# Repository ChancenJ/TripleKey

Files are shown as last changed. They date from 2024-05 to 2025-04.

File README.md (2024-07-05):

# TripleKey

## 项目说明

基于ESP32-S3的蓝牙小键盘，具有时间显示、天气预报、实时股票、宏键盘、蓝牙键盘、倒计时、人在感应、米家智能家居控制等功能。

立创开源地址：[嘉立创EDA开源硬件平台](https://oshwhub.com/chancenj/superkey)

Github地址：[Gituhb](https://github.com/ChancenJ/TripleKey)

Gitee地址：[Gitee](https://gitee.com/chancenj/triplekey)

## 开源协议

CC BY-NC-SA 4.0（署名-非商业性使用-相同方式共享 4.0 国际）

## 项目功能

- 时间显示、实时天气、天气预报、气象预警、实时股票等信息显示。
- 蓝牙键盘、宏键盘、快捷键、快捷网页、媒体控制等控制电脑功能。
- 倒计时等计时功能。
- 通过网页对多项功能自定义配置。
- 【可选，需N16R2】照片轮播功能。
- 【可选，需额外硬件】接入米家，作为米家无线开关和状态寄存器。
- 【可选，需额外硬件】人体存在感应，有人时自动亮屏，无人时自动熄屏，有无人状态接入米家，可搭配米家智能家居设备进行智能联动。

功能展示：[功能展示](https://b23.tv/3Hd1zba)

主体装配视频：[主体装配视频](https://b23.tv/uhOZp0Y)

米家拓展详解：[米家拓展详解](https://b23.tv/kM9jVT6)

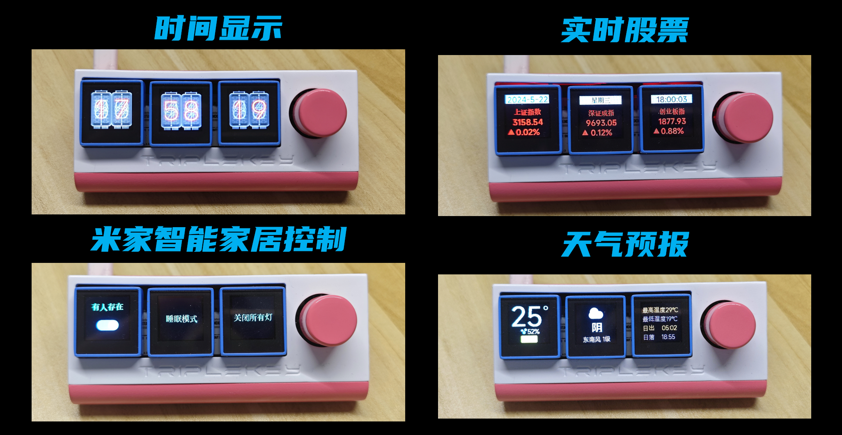
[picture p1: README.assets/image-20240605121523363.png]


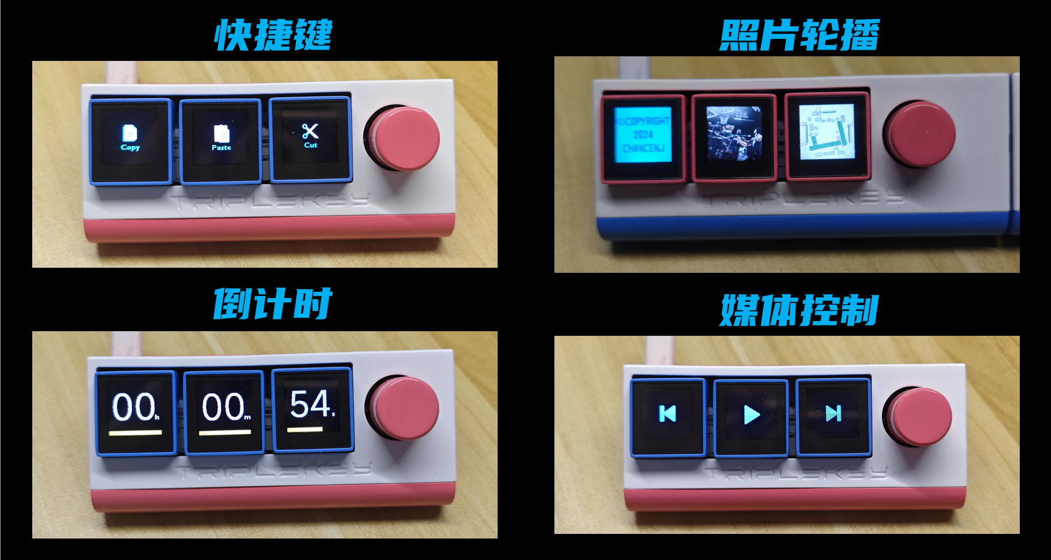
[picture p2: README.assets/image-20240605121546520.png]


## 项目属性

本项目衍生自MakerM0的开源项目[3Plus_v2](https://github.com/MakerM0/3Plus_v2)，优化了PCB布局，替换部分器件，引出拓展接口，增加米家拓展部分，接入米家平台，增加人体存在传感器；更换屏幕方案，大幅降低屏幕成本；重新设计外壳，增加米家拓展部分外壳；在其代码框架基础上增加实时天气、天气预报、气象灾害预警、实时股票信息、米家设备控制、照片轮播、倒计时、WebServer自定义配置、网页后台、人体存在检测、固件检测升级，增加中文UI，优化快捷键功能，优化部分代码结构，修复时钟和快捷网页BUG，修复开机闪屏，去除冗余代码。

仅对源代码进行比较（不包含引用库文件，未包含更多所需data变化），根据git数据，原项目总计7277行，本项目总计12676行，相比变化10117行，其中增加7758行，删除2359行。详见附录。



## 硬件准备

### 硬件说明

#### 主控

ESP32-S3-WROOM-1-N8R2或ESP32-S3-WROOM-1-N16R2。区别在于后者拥有更多ROM，可实现更多功能。当前N16R2对应固件额外支持照片轮播，可自行上传照片在屏幕上显示。建议使用成本略高的N16R2，8MB版本受限于其空间，可能不再更新固件。

#### 旋转编码器

立创EDA中使用阿尔卑斯阿尔派EC11J1524413，成本高昂。若需要降低成本，可选择廉价普通插件编码器改贴片，详见后文额外BOM表。区别在于质感和焊接方式，编码器限位值和正反方向不同，可进行自定义配置。

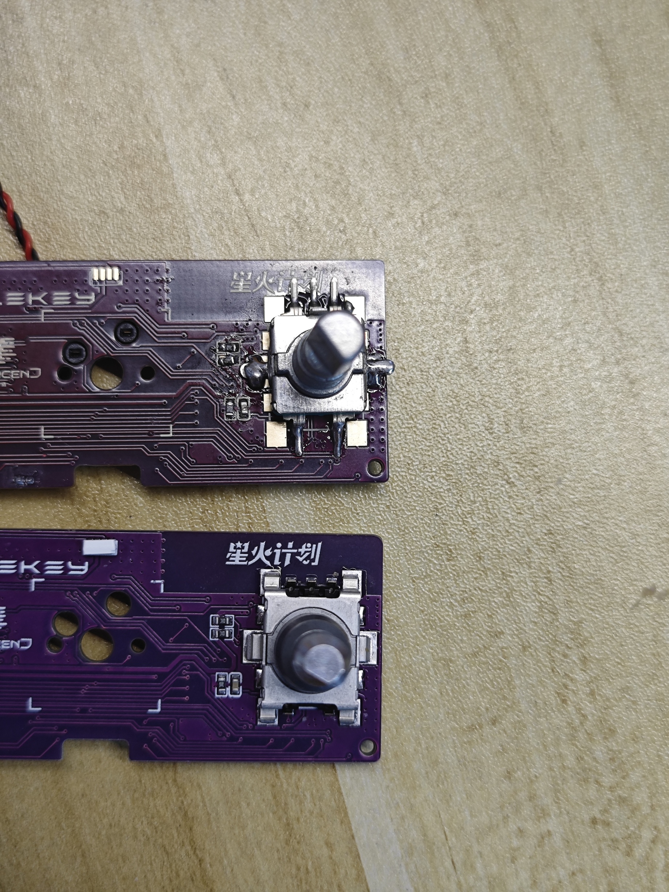
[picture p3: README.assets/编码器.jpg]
编码器


#### 屏幕

- 方案一：0.85英寸长排焊接12PIN（驱动GC9107）直达链接：https://m.tb.cn/h.gXZoDytOg9CEca7?tk=Qb9vWtzlGgj

此方案一定需要定位板，焊接及组装方式详见后文。

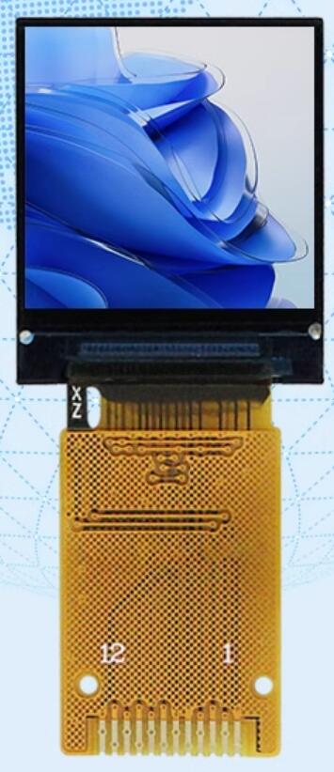
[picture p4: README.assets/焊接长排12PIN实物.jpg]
焊接长排12PIN实物
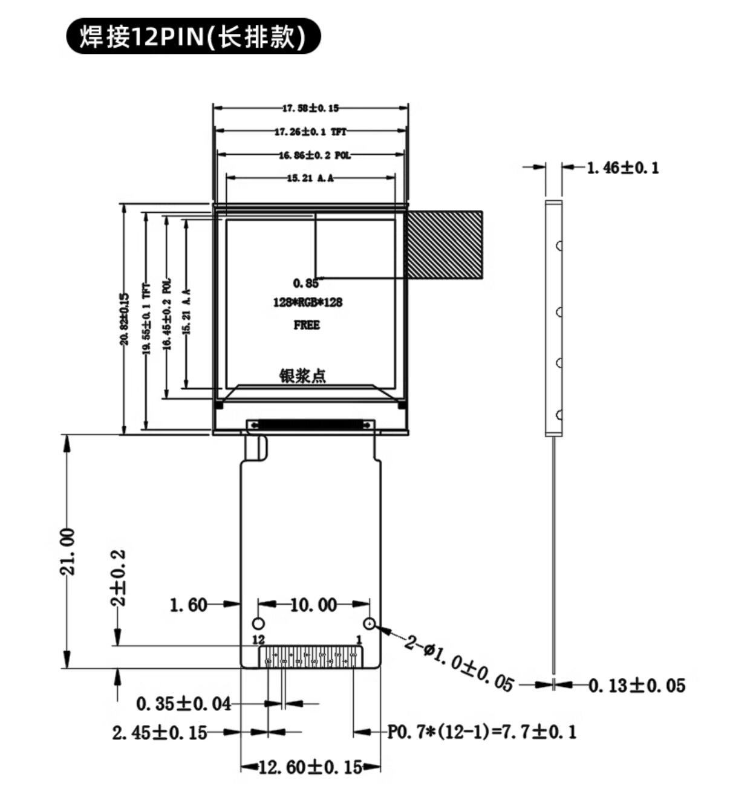
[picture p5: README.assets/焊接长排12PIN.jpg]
焊接长排12PIN


- 方案二：0.85英寸长排插接12PIN（驱动NV3023）直达链接：https://m.tb.cn/h.gc6dU3OZHkynqdG?tk=nWm8WtzFscl

此方案定位板非必须，但为了按键稳固，依然推荐使用定位板但无需焊接，组装方式详见后文。

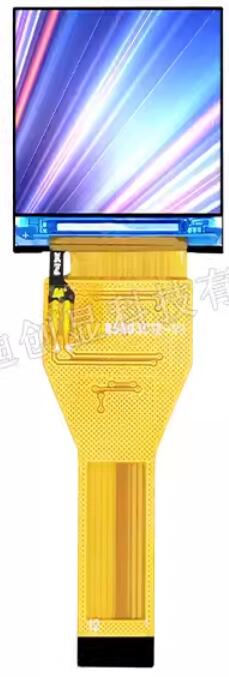
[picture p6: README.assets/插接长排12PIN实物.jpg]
插接长排12PIN实物
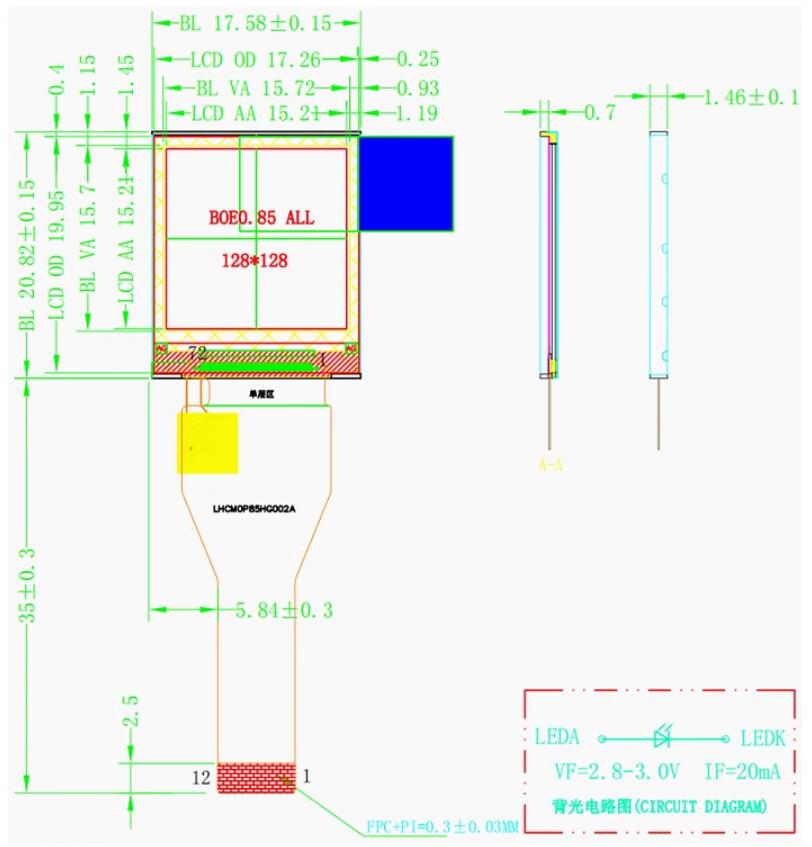
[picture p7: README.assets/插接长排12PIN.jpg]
插接长排12PIN


==区别在于两者成本，方案一成本约15元，但需要焊接屏幕和FPC排线座，方案二成本约30元，直接插接主板。两者固件不同，功能一致。==

### 硬件准备

#### PCB

PCB共分为主板、定位板、拓展板，工程中已标明。

主板必备，定位板强烈推荐（屏幕方案一必备），拓展板可选（用于接入米家和人在感应）。

**主板**

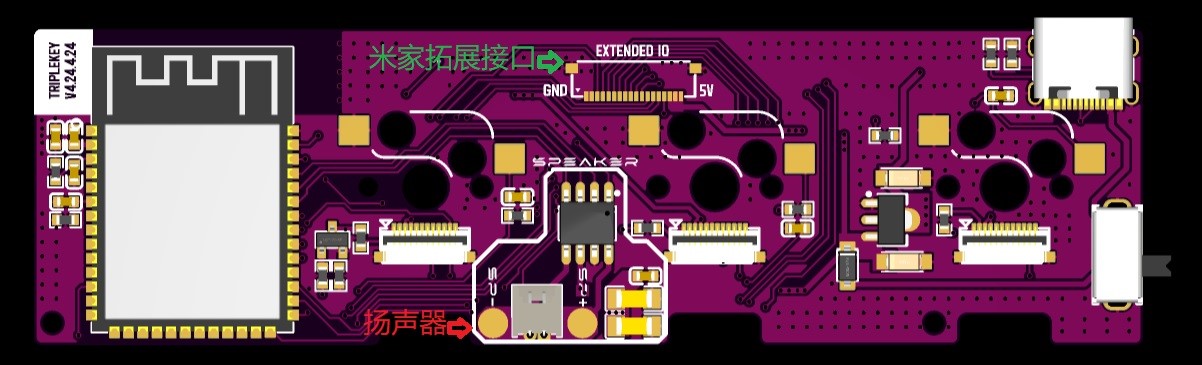
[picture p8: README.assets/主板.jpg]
主板


扬声器与米家拓展接口已标出，可选择性焊接。

**定位板**

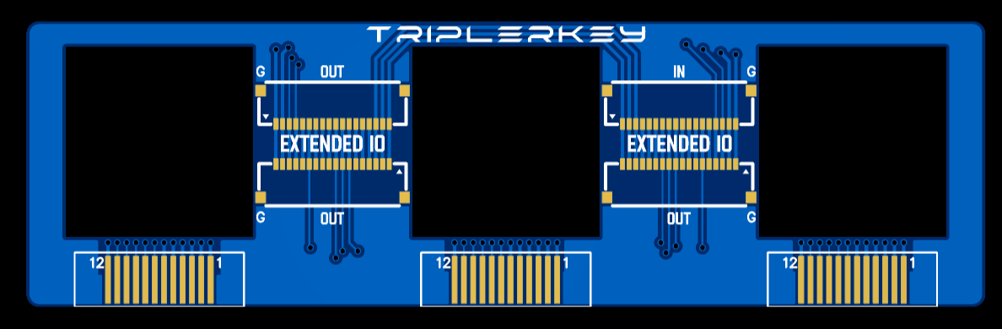
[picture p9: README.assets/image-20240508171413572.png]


用于固定键轴和方案一的屏幕连接。（方案一如下图所示焊接屏幕、安装键轴，屏幕方案二无需焊接）

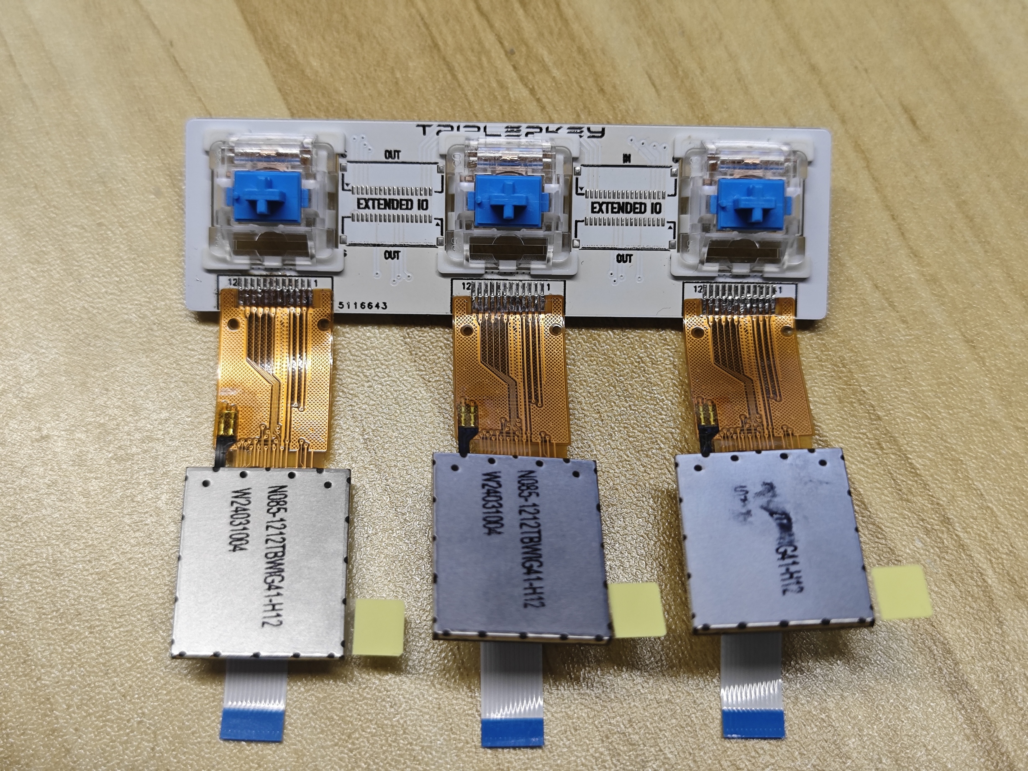
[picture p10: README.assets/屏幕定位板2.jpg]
屏幕定位板2


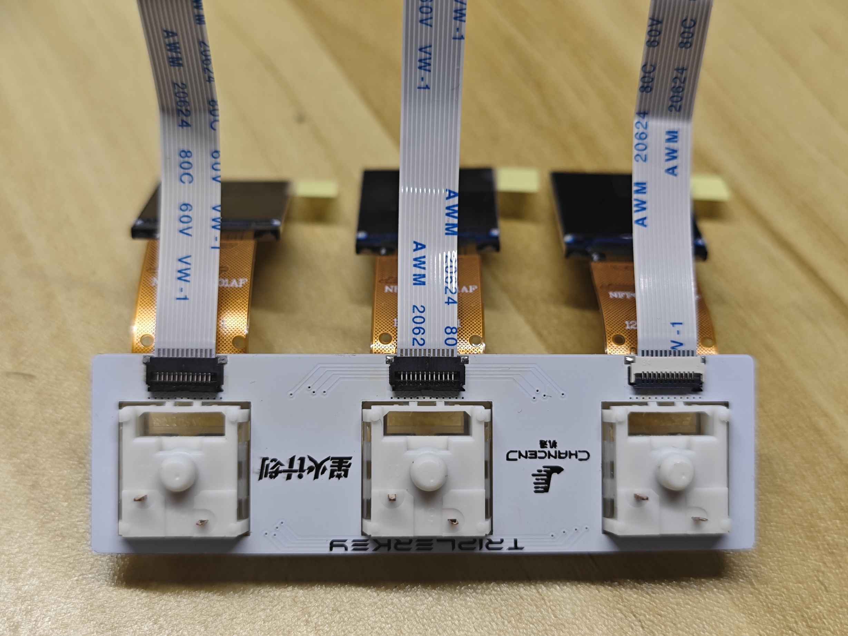
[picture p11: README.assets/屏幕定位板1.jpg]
屏幕定位板1


**米家拓展板**

------

- 20240605更新

对米家拓展方案进行了改进，放入一个外壳，详见[TripleKey小键盘米家拓展方案改进版](https://oshwhub.com/chancenj/triplekey_v2_1)。

**如果你看到了此段内容，不管是否需要米家，都推荐直接使用改进版，只有米家拓展方案不同。**

**改进内容**

将主板与拓展板放入一个外壳，改用**HLK-LD2410B**（[直达链接](https://m.tb.cn/h.g484iFO)）作为人体存在传感器。

如果在原项目中使用了**拓展方案2**进行3D打印，可直接打板**【拓展方案3】米家及人在传感器拓展_贴**放入原外壳。

如果需要对外壳重新3D打印，请改用本项目改版外壳（仅主体外壳不同），打板**【拓展方案3】米家及人在传感器拓展_插**适用新外壳。（贴片版也可使用，但插件排母更方便购买）

主要区别为排母是贴片还是插件，原版拓展方案2外壳受限于支撑PCB部分形状，只能使用贴片排母；新版外壳进行了挖空，贴片排母与插件排母均可使用。

详细解释与装配视频：[米家拓展详解](https://b23.tv/kM9jVT6)

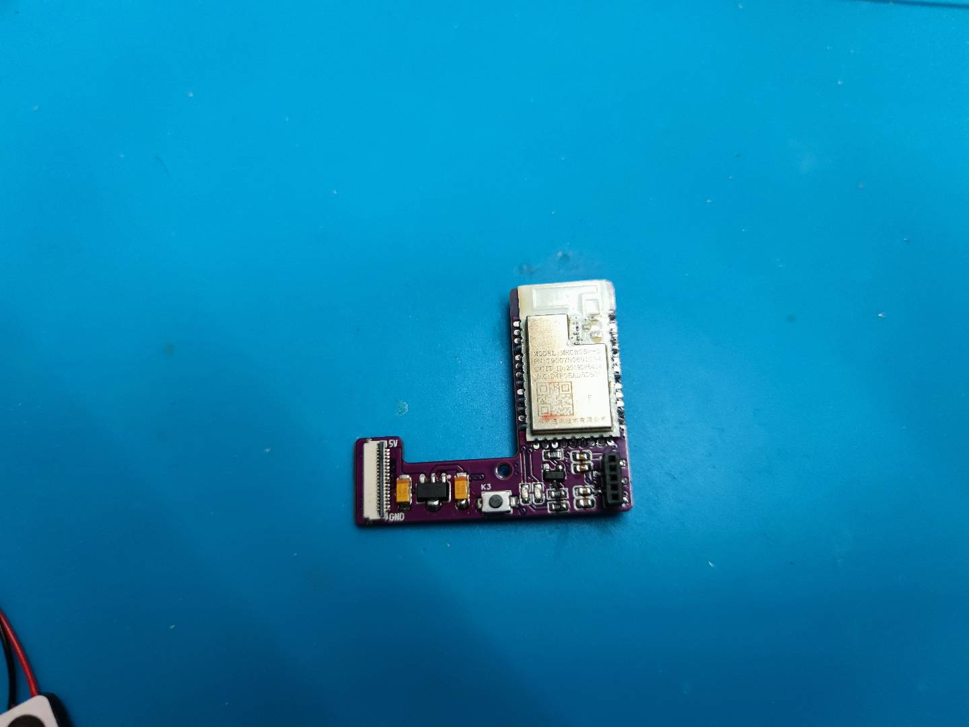
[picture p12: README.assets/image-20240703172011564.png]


------

#### 3D打印外壳

附件下载外壳文件进行打印。

如果使用拓竹等常见FDM3D打印机，请使用FDM版本。

如果在嘉立创3D打印下单，请使用SLA版本。

------

- 20240605更新

对米家拓展方案进行了改进，放入一个外壳，详见[TripleKey小键盘米家拓展方案改进版](https://oshwhub.com/chancenj/triplekey_v2_1)，原版方案2外壳依旧可用。

**如果你看到了此段内容，不管是否需要米家，都推荐直接使用改进版，只有米家拓展方案不同。**

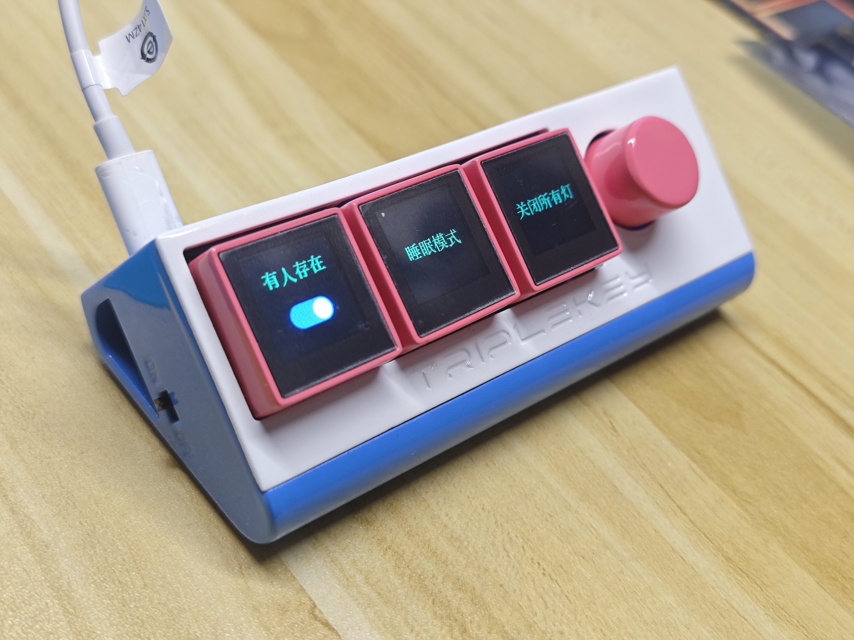
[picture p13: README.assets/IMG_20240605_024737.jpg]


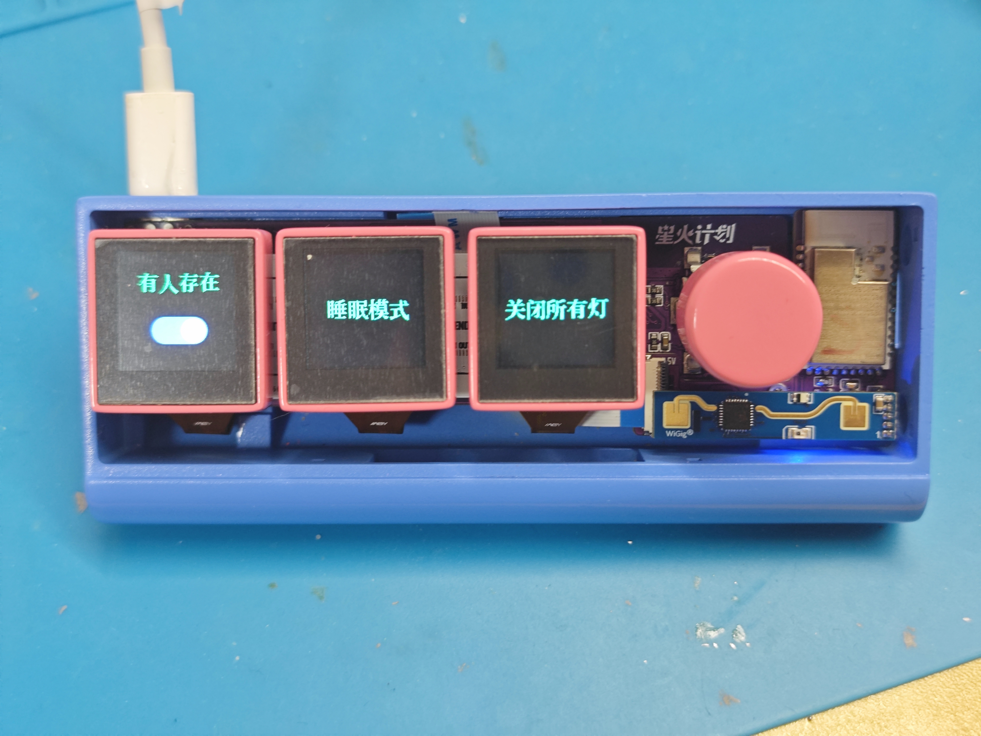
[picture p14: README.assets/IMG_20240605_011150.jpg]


------

#### 面板

使用工程中面板文件，自行选择修改需要的颜色和方案，删掉不需要的颜色，进行面板下单。

设置如下图：（注意：立创面板定制已改版，不再限制尺寸，未实践过新版）

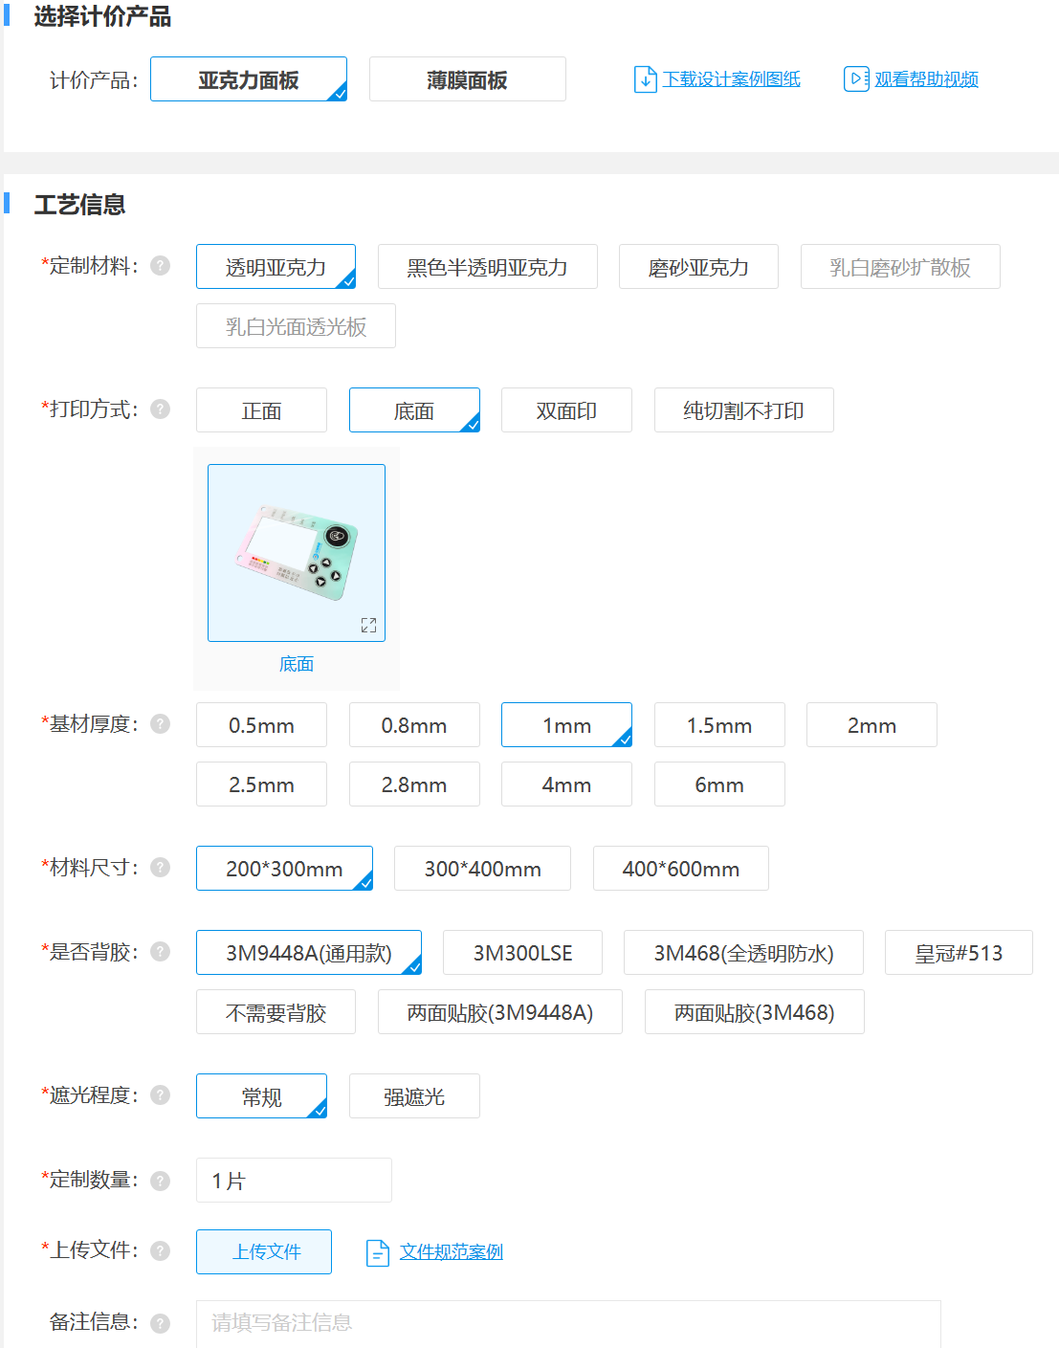
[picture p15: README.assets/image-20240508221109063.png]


#### 额外BOM

[docs目录下额外BOM.xlsx文件](./docs)

表中不包含阻容、二极管、稳压器等常见器件，自行根据立创导出的BOM解决。多数器件可在优信电子买到。

## 软件说明

### 固件烧录

使用乐鑫的[flash download tool](https://www.espressif.com.cn/sites/default/files/tools/flash_download_tool_3.9.5_0.zip)工具，固件有多个版本，根据自身硬件自行选择适配版本。

| 主控 | 屏幕 | 固件 |
| --- | --- | --- |
| ESP32-S3-WROOM-1-N16R2 | NV3023 | firmware_NV3023_16MB.bin |
| ESP32-S3-WROOM-1-N16R2 | GC9107 | firmware_GC9107_16MB.bin |
| ESP32-S3-WROOM-1-N8R2  | NV3023 | firmware_NV3023_8MB.bin  |
| ESP32-S3-WROOM-1-N8R2  | GC9107 | firmware_GC9107_8MB.bin  |

按照下图方式进行安装

1. 在上电前，按住左数第三个按钮，然后上电，进入烧录模式，会听到设备管理器提示音。
2. 打开工具，按下图设置。
3. 下载成功后，手动开关重启，按照提示进行连接设备热点配置WIFI。

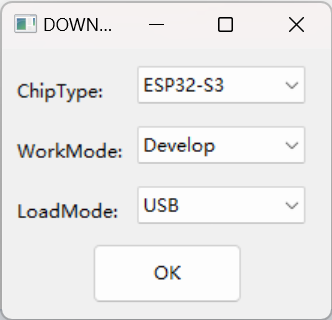
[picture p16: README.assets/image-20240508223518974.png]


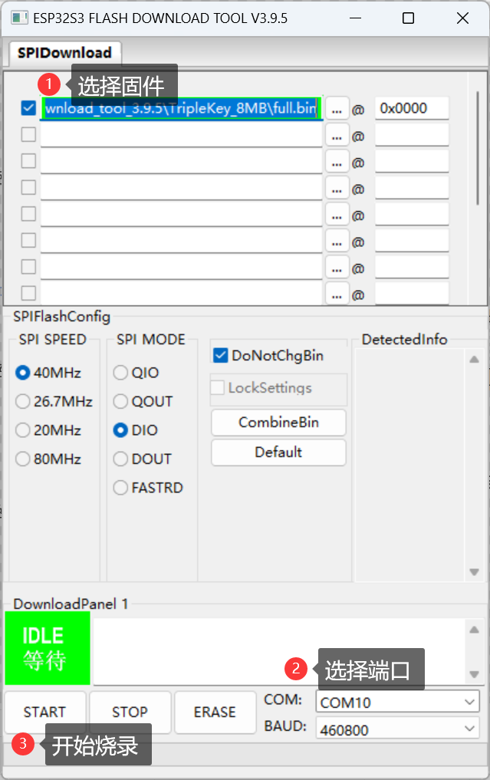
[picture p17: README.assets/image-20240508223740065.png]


### 开始使用

固件烧录完成后开机，连接设备自带热点，进入屏幕提示网址（手机连接后一般自动进入）配置WIFI。启动时按住中键可重新配置，启动时按住右键可进入OTA模式。

连接电脑蓝牙即可使用。

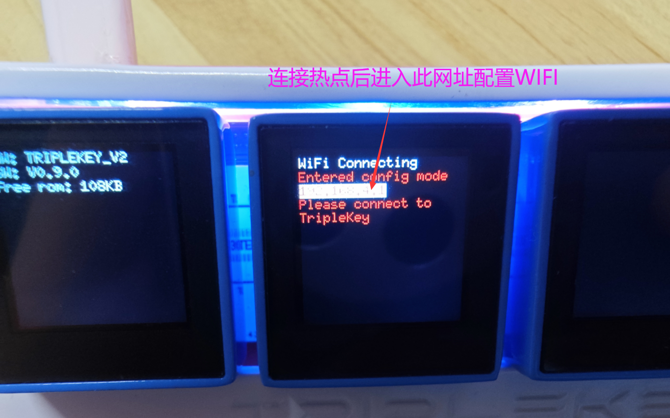
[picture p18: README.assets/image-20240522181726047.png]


### 功能说明与更新日志

详见[软件说明](./Software/README.md)

## 实物展示

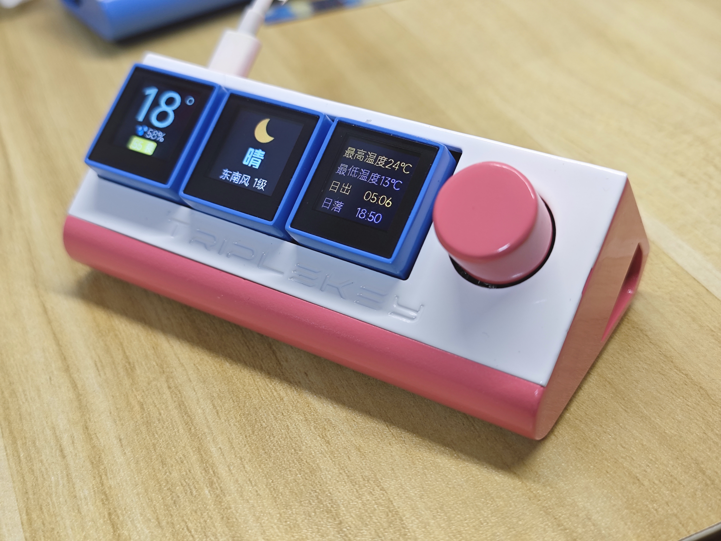
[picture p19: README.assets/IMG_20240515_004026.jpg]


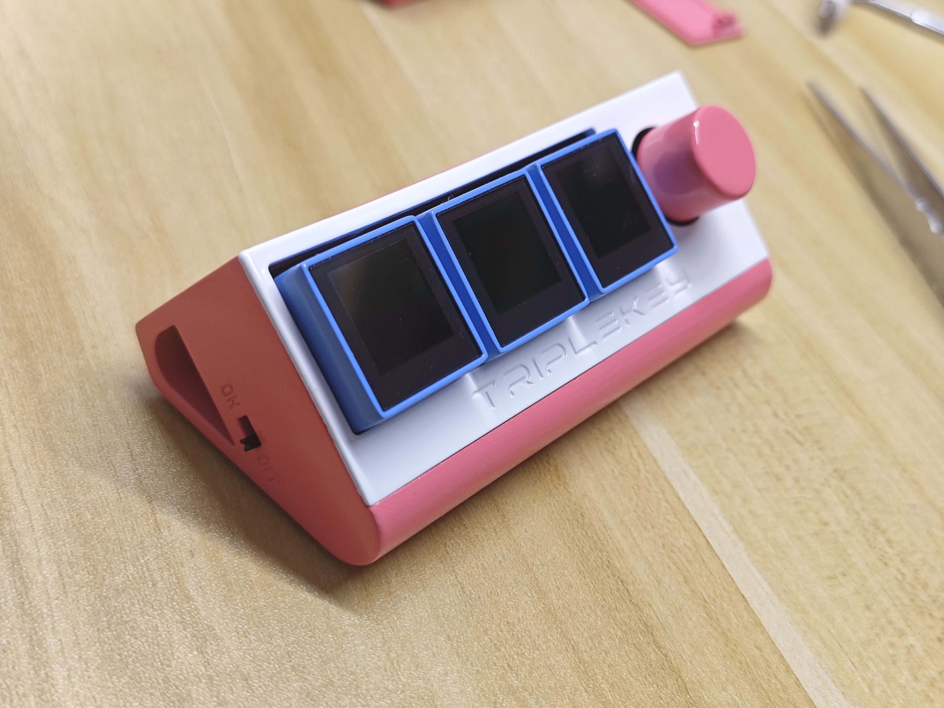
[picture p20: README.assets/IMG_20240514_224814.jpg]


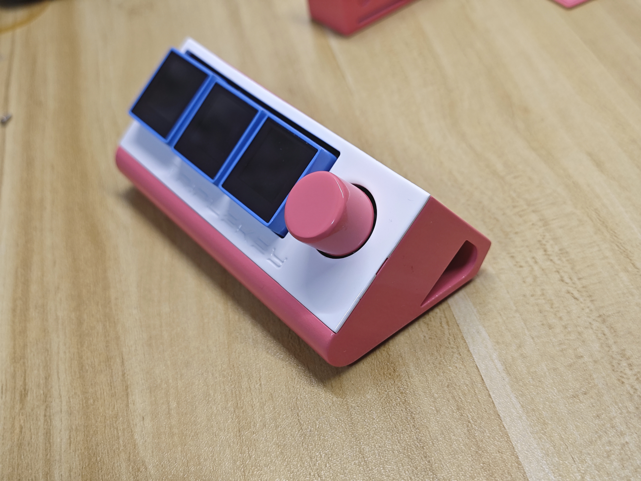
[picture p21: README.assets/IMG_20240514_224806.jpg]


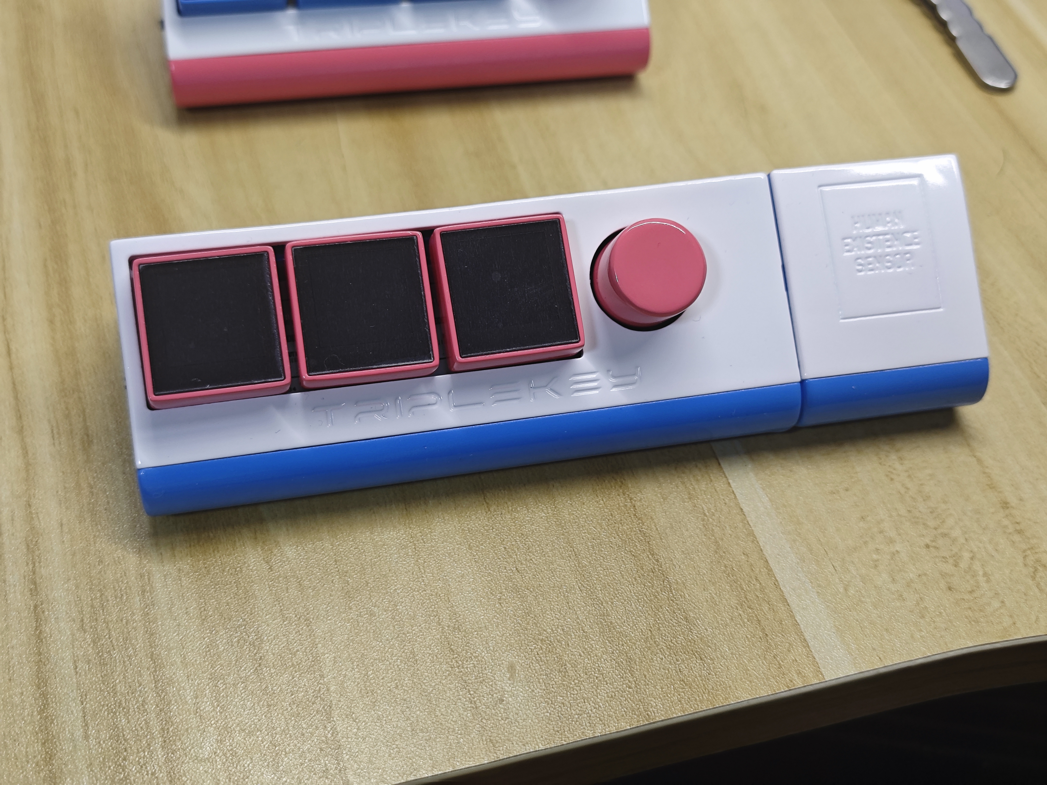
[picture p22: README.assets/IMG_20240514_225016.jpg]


## 附录

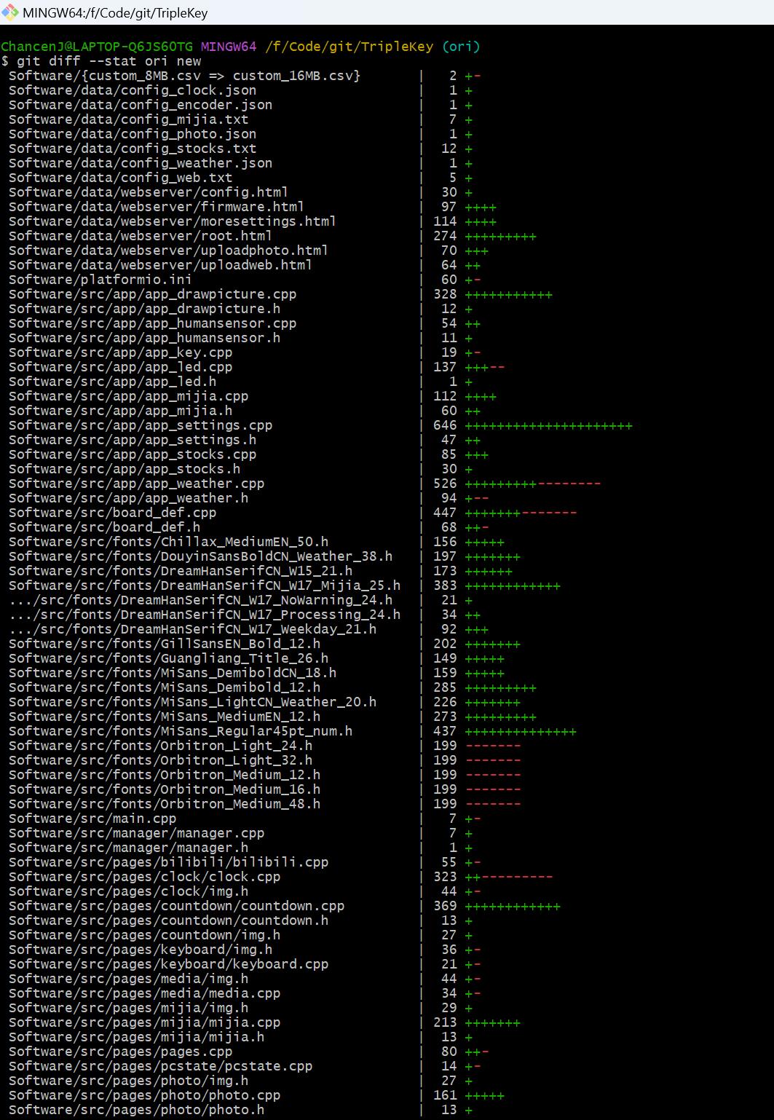
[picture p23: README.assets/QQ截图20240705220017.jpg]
QQ截图20240705220017


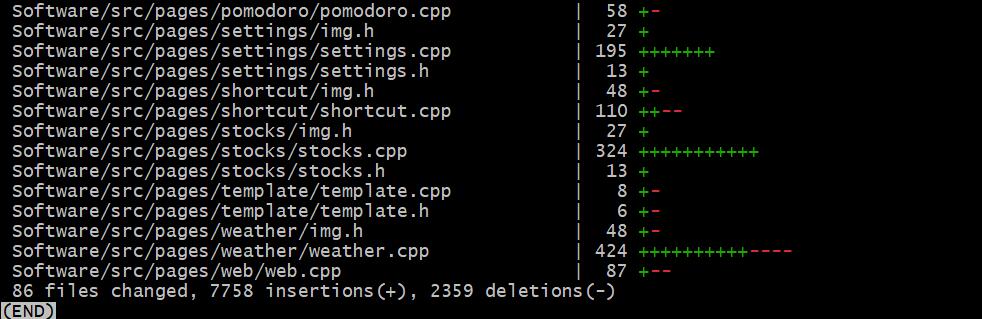
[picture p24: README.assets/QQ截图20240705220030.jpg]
QQ截图20240705220030


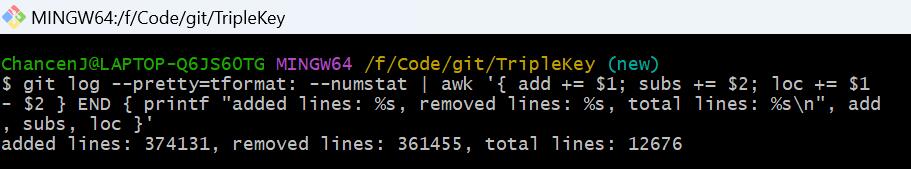
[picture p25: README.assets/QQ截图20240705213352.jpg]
QQ截图20240705213352


QQ截图20240705220120

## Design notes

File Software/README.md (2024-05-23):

## 软件说明

### 功能说明

#### 0.启动

- 首次启动，屏幕提示连接自身热点，进行WIFI配置。启动时按住中键可重新配置，启动时按住右键进入OTA模式。

- 启动后任意页面长按旋钮，进入菜单；旋转旋钮，调整内容；单击对应按键，进入相应页面。

#### 1.时间

| 按键/操作 | 单击 | 双击 | 长按 | 左旋 | 右旋 |
| :---: | :--: | :---: | :---: | :---: | :---: |
| **左键**  | | 进入天气 | 进入米家 | —— | —— |
| **中键**  | 报时 | | | —— | —— |
| **右键**  | | | | —— | —— |
| **旋钮**  | | | 进入菜单 | 调整样式 | 调整样式 |

#### 2.天气

- 实时天气、三日天气预报、气象灾害预警

| 按键/操作 | 单击 | 双击 | 长按 | 左旋 | 右旋 |
| :---: | :---: | :--: | :---: | :---: | :---: |
| **左键**  | | | | —— | —— |
| **中键**  | | | | —— | —— |
| **右键**  | | | | —— | —— |
| **旋钮**  | 返回时间页面 | | 进入菜单 | 调整显示内容 | 调整显示内容 |

#### 3.股票

- 2分钟更新一次数据，自动轮播。呼吸灯颜色随涨跌变化。

| 按键/操作 | 单击 | 双击 | 长按 | 左旋 | 右旋 |
| :---: | :--: | :--: | :---: | :---: | :---: |
| **左键**  | | | | —— | —— |
| **中键**  | | | | —— | —— |
| **右键**  | | | | —— | —— |
| **旋钮**  | | | 进入菜单 | 调整显示内容 | 调整显示内容 |

#### 4.米家（对应固件、连接拓展）

- 米家无线开关功能（米家八键复合开关4情景+4开关），可接入米家控制米家智能家居设备，可显示开关状态，与米家同步，共可设置4开关+12场景（4键单击双击长按）；
- 人体存在传感器（海凌科人体存在传感器HLK-2410C），绑定米家无线开关KEY1，有人存在则KEY1开，无人则KEY1关，有人无人状态实时同步，通过米家可设置智能场景联动米家设备。（有人无人检测相关配置使用海凌科官方APP HLKRadarTool）
- 根据有人无人状态自动开关屏幕和LED灯功能。

| 按键/操作 | 单击 | 双击 | 长按 | 左旋 | 右旋 |
| :---: | :---: | :--: | :---: | :---: | :---: |
| **左键**  | 对应操作 | | | —— | —— |
| **中键**  | 对应操作 | | | —— | —— |
| **右键**  | 对应操作 | | | —— | —— |
| **旋钮**  | 返回时间页面 | | 进入菜单 | 调整操作内容 | 调整操作内容 |

#### 5.照片（ESP32-S3-WROOM-1-N16R2支持，N8R2不支持）

-  通过网页上传，自动轮播

| 按键/操作 | 单击 | 双击 | 长按 | 左旋 | 右旋 |
| :---: | :--: | :--: | :---: | :---: | :---: |
| **左键**  | | | | —— | —— |
| **中键**  | | | | —— | —— |
| **右键**  | | | | —— | —— |
| **旋钮**  | | | 进入菜单 | 调整显示内容 | 调整显示内容 |

#### 6.键盘

- 通过蓝牙连接电脑，用作蓝牙键盘

| 按键/操作 | 单击 | 双击 | 长按 | 左旋 | 右旋 |
| :---: | :---: | :--: | :---: | :---: | :---: |
| **左键**  |  输入对应字符  | | | —— | —— |
| **中键**  |  输入对应字符  | | | —— | —— |
| **右键**  |  输入对应字符  | | | —— | —— |
| **旋钮**  | 切换大小写数字 | | 进入菜单 | 调整显示内容 | 调整显示内容 |

#### 7.快捷键

- 通过蓝牙连接电脑，使用快捷键（复制、剪切、粘贴、显示桌面、全选、切屏、撤销、刷新等）

| 按键/操作 | 单击 | 双击 | 长按 | 左旋 | 右旋 |
| :---: | :---: | :--: | :---: | :---: | :---: |
| **左键**  | 对应快捷键 | | | —— | —— |
| **中键**  | 对应快捷键 | | | —— | —— |
| **右键**  | 对应快捷键 | | | —— | —— |
| **旋钮**  | | | 进入菜单 | 调整显示内容 | 调整显示内容 |

#### 8.网页

-  通过蓝牙连接电脑，快捷启动浏览器进入网页。

| 按键/操作 | 单击 | 双击 | 长按 | 左旋 | 右旋 |
| :---: | :---: | :--: | :---: | :---: | :---: |
| **左键**  | 进入对应网页 | | | —— | —— |
| **中键**  | 进入对应网页 | | | —— | —— |
| **右键**  | 进入对应网页 | | | —— | —— |
| **旋钮**  | | | 进入菜单 | 调整显示内容 | 调整显示内容 |

#### 9.多媒体

- 通过蓝牙连接电脑，控制播放暂停、下一首、上一首、音量。

| 按键/操作 | 单击 | 双击 | 长按 | 左旋 | 右旋 |
| :---: | :---: | :--: | :---: | :---: | :---: |
| **左键**  | 上一首 | | | —— | —— |
| **中键**  | 播放/暂停 | | | —— | —— |
| **右键**  | 下一首 | | | —— | —— |
| **旋钮**  | 静音/解除静音 | | 进入菜单 | 调低音量 | 调高音量 |

#### 10.哔哩哔哩

- 一键三连、开关弹幕、全屏观看

| 按键/操作 | 单击 | 双击 | 长按 | 左旋 | 右旋 |
| :---: | :---: | :--: | :---: | :---: | :---: |
| **左键**  | 一键三连 | | | —— | —— |
| **中键**  | 开关弹幕 | | | —— | —— |
| **右键**  | 全屏观看 | | | —— | —— |
| **旋钮**  | 静音/解除静音 | | 进入菜单 | 调低音量 | 调高音量 |

#### 11.倒计时

- 双击旋钮进入设置模式，按下时分秒对应按键，数字闪烁，旋转旋钮可调节设定时间，单击旋钮开始/暂停/继续，退出倒计时页面继续计时。
- 底部进度条

| 按键/操作 | 单击 | 双击 | 长按 | 左旋 | 右旋 |
| :---: | :---: | :---: | :---: | :---: | :---: |
| **左键**  |  设置时 | | | —— | —— |
| **中键**  |  设置分 | | | —— | —— |
| **右键**  |  设置秒 | | | —— | —— |
| **旋钮**  | 开始/暂停 | 进入设置模式 | 进入菜单 | 调小设定时间 | 调大设定时间 |

#### 12.番茄钟

| 按键/操作 | 单击 | 双击 | 长按 | 左旋 | 右旋 |
| :---: | :---: | :--: | :---: | :--: | :--: |
| **左键**  | 计时开始/暂停 | | |  ——  |  ——  |
| **中键**  | 计时开始/暂停 | | |  ——  |  ——  |
| **右键**  | 计时开始/暂停 | | |  ——  |  ——  |
| **旋钮**  | | | 进入菜单 | | |

#### 13.设置

- 根据屏幕提示进入网页，进行自定义设置，可进行天气、股票、米家、快捷网页、上传照片、编码器等设置。

| 按键/操作 | 单击 | 双击 | 长按 | 左旋 | 右旋 |
| :---: | :---: | :--: | :---: | :--: | :--: |
| **左键**  |  快捷进入设置页面  | | |  ——  |  ——  |
| **中键**  | | | 重启设备 |  ——  |  ——  |
| **右键**  | 快捷进入仓库发行版 | | |  ——  |  ——  |
| **旋钮**  | | | 进入菜单 | | |

### 更新历史

#### 20240320 【V0.0.1】

- 初始版本

#### 20240326 【V0.1.x】

- V0.1.0 增加实时股票功能，股票页显示当前时间、股票名称、当前价格、涨跌幅，每2分钟更新一次，股票页每10秒自动切换，旋钮可手动切换。
- v0.1.1 增加股票页红绿呼吸灯，上涨为红，下跌为绿。
- V0.1.3 股票页显示日期、星期、时间。

#### 20240329 【V0.2.x】

- V0.2.0 天气功能完全重构，采用和风天气API，开机时长按中间键进入WIFI配置页可配置城市（输入拼音）和密钥（和风天气官网免费获取）。天气页显示当前温度、相对湿度、空气质量、天气状况、风向风力、最高最低温度、日出日落时间，旋钮可切换显示三天天气预报。

#### 20240410 【V0.3.x】

- V0.3.0 增加米家无线开关功能（米家八键复合开关4情景+4开关），可接入米家控制米家智能家居设备，可显示开关状态，与米家同步，共可设置4开关+12场景（4键单击双击长按）；增加人体存在传感器，绑定米家无线开关KEY1，有人存在则KEY1开，无人则KEY1关，有人无人状态实时同步，通过米家可设置智能场景联动米家设备。（*增加硬件：米家八键复合开关模组MHCB05P-B、海凌科人体存在传感器HLK-2410C、I2C拓展芯片CH423S。集合为米家拓展配件，通过拓展外设插口接入）
- V0.3.8 增加根据有人无人状态自动开关屏幕和LED灯功能。（有人无人检测相关配置使用海凌科官方APP HLKRadarTool）

#### 20240418 【V0.4.x】

- V0.4.0 增加自定义配置功能，连接WIFI后，进入设置页面，可在浏览器输入IP地址或扫描二维码进入配置页，对天气、股票、米家、快捷网页进行自定义配置，保存后即时生效。
- V0.4.3 增加整点报时可选项（更多设置Web页）。
- V0.4.4 增加时钟主题自动切换可选项。
- V0.4.10 增加旋转编码器设置，设置WIFI时或进入设置页-更多设置可对旋转编码器进行配置，旋转编码器限位值为2（阿尔卑斯阿尔派EC11J1524413）或4（普通插改贴编码器），若编码器操作逻辑相反，可设置反向。

#### 20240504 【V0.5.x】

- V0.5.0 【N16R2适配功能】增加照片播放功能，可进入设置页-更多设置对照片进行上传和删除，可设置是否自动轮播。

#### 20240505 【V0.6.x】

- V0.6.0 天气功能增加气象灾害预警信息

#### 20240506 【V0.7.x】

- V0.7.0 增加倒计时功能，双击旋钮进入设置模式，按下时分秒对应按键，数字闪烁，旋转旋钮可调节设定时间，单击旋钮开始/暂停/继续，退出倒计时页面继续计时。

#### 20240511 【V0.8.x】

- V0.8.0 重构人体存在传感器与米家开关运行机制，多线程运行，米家开关操作增加消息队列，可连续处理多个操作。

#### 20240513 【V0.9.x】

- V0.9.0 支持固件版本检测，开机时将检查是否有新版本固件，若有新版本则屏幕提示，进入Web设置页-下载固件可根据自身硬件下载对应固件。

#### 20240523 【V1.0.0】

- V1.0.0 正式发布版

### 后续计划

- 增加整合信息页
- 使用LVGL重构全部UI
- 优化Web设置页面

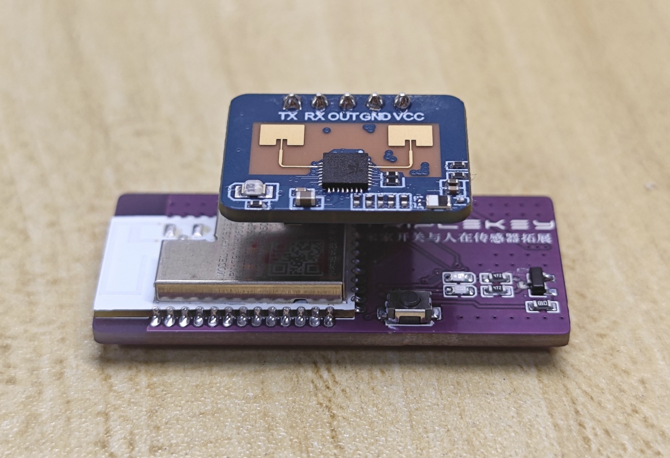
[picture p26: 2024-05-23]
README.assets/拓展方案1.jpg

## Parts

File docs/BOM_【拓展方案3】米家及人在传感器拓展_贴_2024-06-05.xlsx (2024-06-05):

No. | Quantity | Comment | Designator | Footprint | Value | Manufacturer Part | Manufacturer | Supplier Part | Supplier | LCSC Price | LCSC Stock | JLCPCB Stock | JLCPCB Price
1 | 2 | 10uF | C1,C2 | CAP-SMD_L3.2-W1.6-RD | 10uF | CA45-A-16V-10uF-K | CEC(振华新云) | C128254 | LCSC | 0.405949 | 45231 | 247874 | 0.406
2 | 2 | 100nF | C3,C4 | C0603 | 100nF | TCC0603X7R104K500CT | CCTC(三环) | C282519 | LCSC | 0.012653 | 47208 | 2555637 | 0.0127
3 | 1 | 0.5K-HX-18PWB | FPC4 | FPC-SMD_18P-P0.50_HDGC_0.5K-HX-18PWB |  | 0.5K-HX-18PWB | HDGC(华德共创) | C2919497 | LCSC | 1.5821 | 4871 | 18823 | 1.582
4 | 1 | BX-TS-16-432T | K3 | KEY-SMD_L3.9-W3.0-LS5.0 |  | BX-TS-16-432T | Bossie(博锡) | C18077679 | LCSC | 0.1533 | 0
5 | 1 | AMS1117-3.3 | LDO1 | SOT-89-3_L4.5-W2.5-P1.50-LS4.1-BL |  | AMS1117-3.3 | YONGYUTAI(永裕泰) | C2904742 | LCSC | 0.373908 | 440 | 1 | 0.374
6 | 2 | XL-1608SURC-06 | LED2,LED3 | LED0603-RD_RED |  | XL-1608SURC-06 | XINGLIGHT(成兴光) | C965799 | LCSC | 0.019439 | 22226 | 1342081 | 0.0194
7 | 1 | SS8050 | Q1 | SOT-23-3_L2.9-W1.3-P1.90-LS2.4-BR |  | SS8050 | AnBon(安邦) | C541705 | LCSC | 0.11923 | 71 | 2811 | 0.119
8 | 2 | 4.7kΩ | R3,R4 | R0603 | 4.7kΩ | FRC0603J472 TS | FOJAN(富捷) | C2907166 | LCSC | 0.004788 | 11198 | 535860 | 0.00479
9 | 1 | CH423S | U1 | SOP-28_L17.9-W7.5-P1.27-LS10.3-BL |  | CH423S | WCH(南京沁恒) | C111663 | LCSC | 2.53 | 892 | 1104 | 2.53
10 | 2 | 10uF | U2,U3 | C0603 | 10uF | CGA0603X5R106K100JT | HRE(芯声) | C6119842 | LCSC | 0.036826 | 9173 | 559606 | 0.0368
11 | 1 | MHCB05P-B | U5 | MHCB05P-B
12 | 1 | 1kΩ | U42 | R0603 | 1kΩ | RC0603FR-071KL | YAGEO(国巨) | C22548 | LCSC | 0.00607 | 82875 | 7142257 | 0.00607
13 | 1 | X1311FVS-05-C43D35R2 | U43 | CONN-SMD_5P-P1.27_XKB_X1311FVS-05-C43D35R2 |  | X1311FVS-05-C43D35R2 | XKB Connectivity(中国星坤) | C2881514 | LCSC | 1.3372 | 109 | 745 | 1.337

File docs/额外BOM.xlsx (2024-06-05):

TripleKey额外BOM表
声明：本表提供链接为本人购买链接，不构成推荐，本人不对此负责，可自行选择合适器件
本表以外所需器件根据立创EDA导出的BOM表购买，全部可在立创商城购买，大多也可在淘宝优信电子买到，自行选择
类型 | 型号 | 数量 | 购买链接 | 立创商城是否出售 | 备注 | 估价
主控（二选一） | ESP32-S3-WROOM-1-N16R2 | 1 | https://m.tb.cn/h.g1ljRNf | 是 | 查看硬件选择部分进行选择 | 20
 | ESP32-S3-WROOM-1-N8R2 | 1 | https://m.tb.cn/h.g1lpZXZ | 是 |  | 18
屏幕（二选一） | 0.85英寸TFT长排焊接12PIN GC9107 | 3 | https://m.tb.cn/h.gcilInXTZlwwZjx?tk=m7huWGbekv0 | 否 | 查看硬件选择部分进行选择 | 16
 | 0.85英寸TFT长排插接12PIN NV3023 | 3 | https://m.tb.cn/h.gciq9r2MAFS9U8M?tk=cWuPWGbS2IL | 否 |  | 30
旋转编码器（二选一） | EC11J1524413 | 1 | 立创商城 | 是 | 查看硬件选择部分进行选择 | 15
 | 半月柄 旋转编码器 开关/EC11/数字电位器 柄长20mm 带开关 5脚 | 1 | https://m.tb.cn/h.gXcP6Mw | 否 |  | 2
键轴 | 十字轴 | 3 | https://m.tb.cn/h.gXZjAG0 | 否 | 立创商城有高昂的凯华键轴 | 7
轴座 | 热插拔轴座底座 凯华CPG1511连接器 | 3 | https://m.tb.cn/h.gXcnoPDHwFPVN7I?tk=YmceWGbKVw5 | 是 |  | 3
防滑脚撑 | 8mm*2mm | 4+ | https://m.tb.cn/h.gcRYusT | 否 |  | 5
螺丝 | M1.6 长5mm | 4 | https://m.tb.cn/h.gXcsMj17hJzisX4?tk=VWT2WGbGh6B | 否 |  | 1
螺母 | M1.6 | 4 | https://m.tb.cn/h.gcR3lOS | 否 |  | 2
以下部分为可选项，根据自身需求购买
FPC排线 | 12P 间隔0.5mm长50mm | 3 | https://m.tb.cn/h.g1AO83d | 否 | 屏幕方案一所需 | 2
功放芯片 | NS4168 | 1 | https://m.tb.cn/h.gcsmIYJ | 否 |  | 2
扬声器 | 0916腔体或其他，1.25mm端子 | 1 | https://m.tb.cn/h.gcRTKYt | 否 | 尺寸小于40*12mm即可 | 6
米家模组 | 米家开关模组，4开关+4场景，MHCB05P-B | 1 | 闲鱼搜索米家模块/模组，找符合的型号 | 否 | 接入米家所需 | 15
人在传感器 | 海凌科HLK-LD2410B | 1 | https://m.tb.cn/h.g484iFO | 否 | 接入米家所需 | 15
FPC排线 | 18P 间隔0.5mm长100mm | 1 | 淘宝自搜 | 否 | 接入米家所需 | 2

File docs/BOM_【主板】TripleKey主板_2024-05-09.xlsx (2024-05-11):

No. | Quantity | Comment | Designator | Footprint | Value | Manufacturer Part | Manufacturer | Supplier Part | Supplier | LCSC Price | LCSC Stock | JLCPCB Stock | JLCPCB Price
1 | 2 | 10uF | C1,C2 | CAP-SMD_L3.2-W1.6-RD | 10uF | CA45-A-16V-10uF-K | CEC(振华新云) | C128254 | LCSC | 0.405949 | 32734 | 181744 | 0.406
2 | 5 | 100nF | C4,C5,C7,C8,C9 | C0603 | 100nF | CL10B104KB8NNNC | SAMSUNG(三星) | C1591 | LCSC | 0.016021 | 279847 | 28178496 | 0.016
3 | 1 | 10uF | C6 | C0603 | 10uF | CL10A106KP8NNNC | SAMSUNG(三星) | C19702 | LCSC | 0.036642 | 17420 | 2132161 | 0.0366
4 | 3 | 1uF | C204,C205,C213 | C0603 | 1uF | CL10A105KB8NNNC | SAMSUNG(三星) | C15849 | LCSC | 0.028523 | 7370 | 3433456 | 0.0285
5 | 2 | 47uF | C214,C215 | C1206 | 47uF | GRM31CR61A476ME15L | muRata(村田) | C94034 | LCSC | 0.417266 | 18630 | 55891 | 0.417
6 | 1 | 1.25-2AW | CN1 | CONN-TH_2P-P1.25_DEALON_1.25-2AW |  | 1.25-2AW | DEALON(德艺隆) | C2904948 | LCSC | 0.072915 | 45 | 2658 | 0.0729
7 | 1 | 1N5819HW-7-F | D1 | SOD-123_L2.7-W1.6-LS3.7-RD |  | 1N5819HW-7-F | DIODES(美台) | C82544 | LCSC | 0.194379 | 10175 | 94294 | 0.194
8 | 3 | AFC42-S12FMA-1H | FPC1,FPC2,FPC3 | CONN-SMD_12P-P0.50_L3.1-W8.0 |  | AFC42-S12FMA-1H | JS(钜硕电子) | C466532 | LCSC | 0.845855 | 5237 | 15362 | 0.846
9 | 1 | 0.5K-HX-18PWB | FPC4 | FPC-SMD_18P-P0.50_HDGC_0.5K-HX-18PWB |  | 0.5K-HX-18PWB | HDGC(华德共创) | C2919497 | LCSC | 1.588 | 4302 | 15960 | 1.588
10 | 1 | AMS1117-3.3 | LDO1 | SOT-89-3_L4.5-W2.5-P1.50-LS4.1-BL |  | AMS1117-3.3 | YONGYUTAI(永裕泰) | C2904742 | LCSC | 0.373908 | 772 | 272 | 0.374
11 | 3 | XL-4020RGBC-WS2812B | LED2,LED3,LED4 | LED-SMD_4P-L4.0-W1.7_M4020-03003-RGB-862-001 |  | XL-4020RGBC-WS2812B | XINGLIGHT(成兴光) | C3647024 | LCSC | 0.791869 | 3425 | 16668 | 0.792
12 | 3 | CPG151101S11-16 | MX1,MX2,MX3 | CherryMX(KHS)-1.00U |  | CPG151101S11-16 | Kailh(凯华) | C5156480 | LCSC | 0.8335 | 0 | 3378 | 0.834
13 | 1 | SS8050 | Q200 | SOT-23-3_L2.9-W1.3-P1.90-LS2.4-BR |  | SS8050 | CJ（江苏长电/长晶） | C2150 | LCSC | 0.090702 | 20887 | 1537862 | 0.0907
14 | 2 | 5.1kΩ | R1,R2 | R0603 | 5.1kΩ | 0603WAF5101T5E | UNI-ROYAL(厚声) | C23186 | LCSC | 0.006222 | 73975 | 3730468 | 0.00622
15 | 8 | 10kΩ | R3,R5,R7,R8,R9,R10,R11,R202 | R0603 | 10kΩ | 0603WAF1002T5E | UNI-ROYAL(厚声) | C25804 | LCSC | 0.005732 | 111555 | 18883032 | 0.00573
16 | 1 | 1kΩ | R201 | R0603 | 1kΩ | 0603WAF1001T5E | UNI-ROYAL(厚声) | C21190 | LCSC | 0.006228 | 111456 | 12929701 | 0.00623
17 | 1 | 1MΩ | R204 | R0603 | 1MΩ | 0603WAF1004T5E | UNI-ROYAL(厚声) | C22935 | LCSC | 0.006301 | 34850 | 1697551 | 0.0063
18 | 3 | 20Ω | R205,R206,R207 | R0603 | 20Ω | 0603WAF200JT5E | UNI-ROYAL(厚声) | C22950 | LCSC | 0.006171 | 6397 | 392614 | 0.00617
19 | 1 | EC11J1524413 | SW102 | SW-SMD_EC11J1524413 |  | EC11J1524413 | ALPSALPINE(阿尔卑斯阿尔派) | C470592 | LCSC | 18.45 | 11 | 31 | 18.45
20 | 1 | SK12D07VG5 | SW108 | SW-TH_SK12D07VG5 |  | SK12D07VG5 | SHOU HAN(首韩) | C431548 | LCSC | 0.128112 | 1116 | 13874 | 0.128
21 | 1 | ESP32-S3-WROOM-1-N16R2 | U205 | WIRELM-SMD_ESP32-S3-WROOM-1 | 2.4GHz | ESP32-S3-WROOM-1-N16R2 | ESPRESSIF(乐鑫) | C2913205 | LCSC | 30.01 | 809 | 911 | 30.01
22 | 1 | NS4168 | U207 | ESOP-8_L4.9-W3.9-P1.27-LS6.0-BL-EP-1 |  | NS4168 |  | C9900042517 | LCSC
23 | 1 | USB-TYPE-C-018 | USB2 | USB-C_SMD-TYPE-C-31-M-12 |  | USB-TYPE-C-018 | DEALON(德艺隆) | C2927038 | LCSC | 0.31507 | 4192 | 28475 | 0.315

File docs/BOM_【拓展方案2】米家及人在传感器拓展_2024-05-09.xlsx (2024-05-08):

No. | Quantity | Comment | Designator | Footprint | Value | Manufacturer Part | Manufacturer | Supplier Part | Supplier | LCSC Price | LCSC Stock | JLCPCB Stock | JLCPCB Price
1 | 1 | 100nF | C3 | C0603 | 100nF | TCC0603X7R104K500CT | CCTC(三环) | C282519 | LCSC | 0.012653 | 24705 | 2353565 | 0.0127
2 | 1 | 2.54-1*5P母 | H1 | HDR-TH_5P-P2.54-V-F |  | 2.54-1*5P母 | BOOMELE(博穆精密) | C50950 | LCSC | 0.3978 | 7107 | 1439 | 0.398
3 | 1 | PZ254R-12-8P | H2 | HDR-TH_8P-P2.54-H-M-R2-C4-S2.54 |  | PZ254R-12-8P | XFCN(兴飞) | C492432 | LCSC | 0.308015 | 899 | 4434 | 0.308
4 | 1 | BX-TS-16-432T | K3 | KEY-SMD_L3.9-W3.0-LS5.0 |  | BX-TS-16-432T | Bossie(博锡) | C18077679 | LCSC | 0.2074 | 0
5 | 2 | XL-1608SURC-06 | LED2,LED3 | LED0603-RD_RED |  | XL-1608SURC-06 | XINGLIGHT(成兴光) | C965799 | LCSC | 0.01932 | 19920 | 1036373 | 0.0193
6 | 1 | SS8050 | Q1 | SOT-23-3_L2.9-W1.3-P1.90-LS2.4-BR |  | SS8050 | AnBon(安邦) | C541705 | LCSC | 0.120902 | 16 | 1 | 0.121
7 | 2 | 4.7kΩ | R3,R4 | R0603 | 4.7kΩ | FRC0603J472 TS | FOJAN(富捷) | C2907166 | LCSC | 0.004788 | 3350 | 336607 | 0.00479
8 | 1 | CH423S | U1 | SOP-28_L17.9-W7.5-P1.27-LS10.3-BL |  | CH423S | WCH(南京沁恒) | C111663 | LCSC | 2.53 | 425 | 425 | 2.53
9 | 1 | 10uF | U2 | C0603 | 10uF | CGA0603X5R106K100JT | HRE(芯声) | C6119842 | LCSC | 0.038768 | 2261 | 231808 | 0.0388
10 | 1 | MHCB05P-B | U5 | MHCB05P-B
11 | 1 | 1kΩ | U42 | R0603 | 1kΩ | RC0603FR-071KL | YAGEO(国巨) | C22548 | LCSC | 0.00614 | 7316 | 45368 | 0.00614

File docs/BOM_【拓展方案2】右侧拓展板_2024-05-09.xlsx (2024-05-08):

No. | Quantity | Comment | Designator | Footprint | Value | Manufacturer Part | Manufacturer | Supplier Part | Supplier | LCSC Price | LCSC Stock | JLCPCB Stock | JLCPCB Price
1 | 2 | 10uF | C1,C2 | CAP-SMD_L3.2-W1.6-RD | 10uF | CA45-A-16V-10uF-K | CEC(振华新云) | C128254 | LCSC | 0.405949 | 34381 | 190805 | 0.406
2 | 2 | 100nF | C3,C4 | C0603 | 100nF | TCC0603X7R104K500CT | CCTC(三环) | C282519 | LCSC | 0.012653 | 24705 | 2353565 | 0.0127
3 | 1 | 0.5K-HX-18PWB | FPC4 | FPC-SMD_18P-P0.50_HDGC_0.5K-HX-18PWB |  | 0.5K-HX-18PWB | HDGC(华德共创) | C2919497 | LCSC | 1.588 | 4314 | 15980 | 1.588
4 | 1 | AMS1117-3.3 | LDO1 | SOT-89-3_L4.5-W2.5-P1.50-LS4.1-BL |  | AMS1117-3.3 | YONGYUTAI(永裕泰) | C2904742 | LCSC | 0.373908 | 949 | 2221 | 0.374
5 | 1 | PM254-2-04-W-8.5 | U1 | HDR-TH_8P-P2.54-H-F-R2-C4-W8.5 |  | PM254-2-04-W-8.5 | HCTL(华灿天禄) | C2897424 | LCSC | 0.9771 | 430 | 273 | 0.977
6 | 2 | 10uF | U2,U3 | C0603 | 10uF | CGA0603X5R106K100JT | HRE(芯声) | C6119842 | LCSC | 0.038768 | 2261 | 231808 | 0.0388

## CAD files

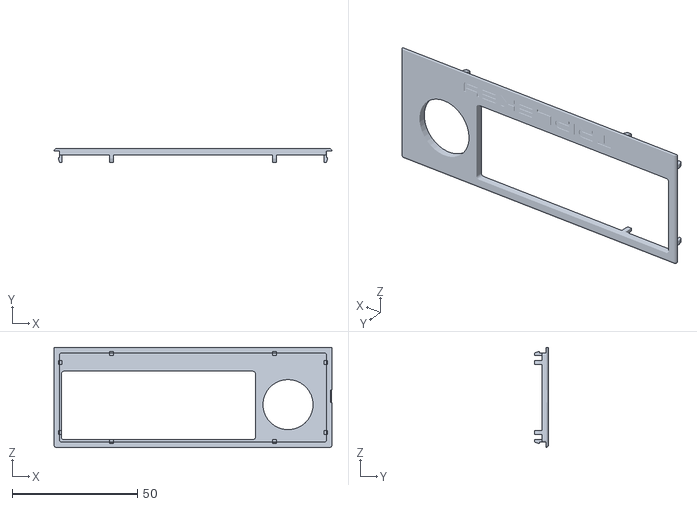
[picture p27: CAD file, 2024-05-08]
3DPrinting/基础版本（无拓展）/外壳盖板.STL
111.0 x 5.50 x 40.0

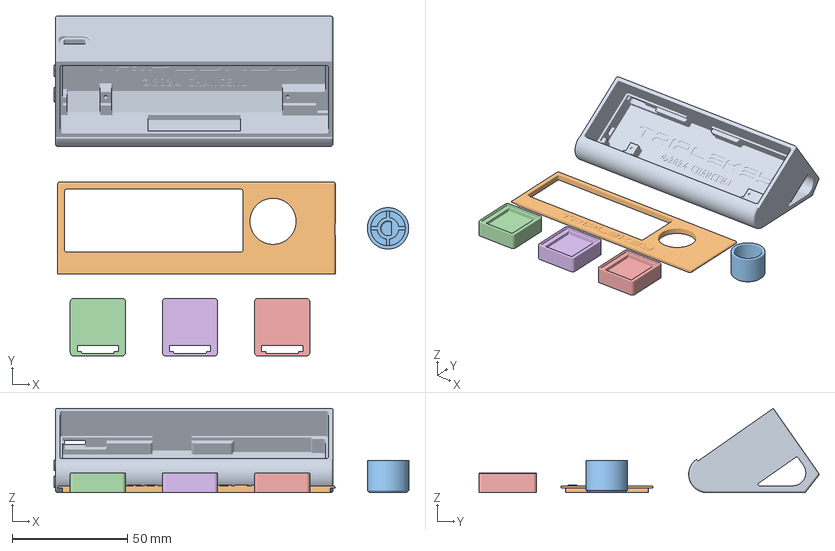
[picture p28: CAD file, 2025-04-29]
3DPrinting/新方案三（★★★推荐★★★）/改进版新方案FDM（适用拓竹等常见打印机）/OrcaSlicer切片摆盘.3mf
153.9 x 147.6 x 36.6 mm
主体外壳.STEP
主体外壳盖板.STEP
旋钮FDM.STEP
按键屏幕FDM.STEP x 3

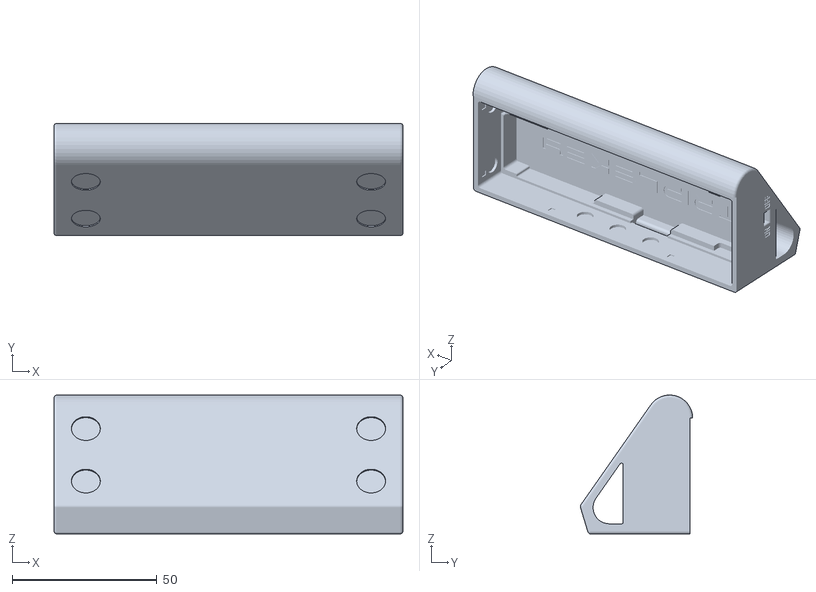
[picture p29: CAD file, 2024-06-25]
3DPrinting/新方案三（★★★推荐★★★）/改进版新方案SLA光固化（适用嘉立创3D打印）/新版主体外壳.STL
120.5 x 38.8 x 48.0

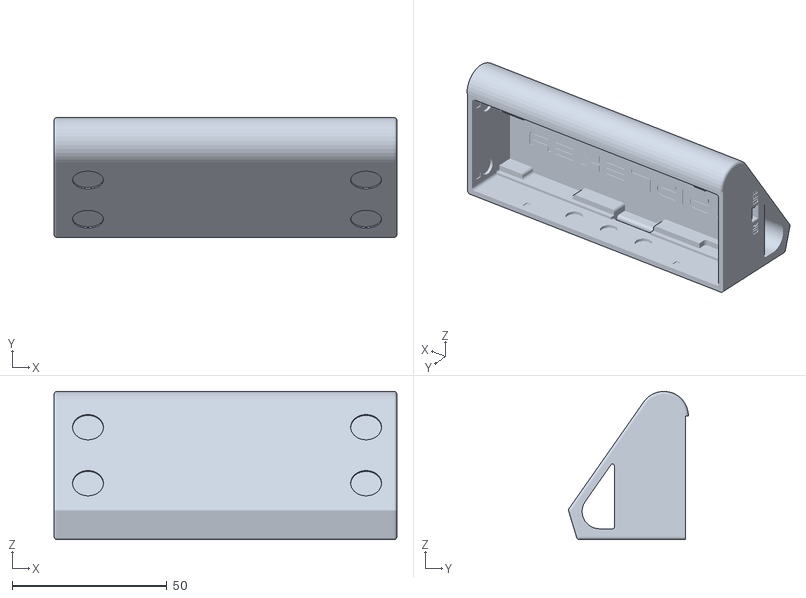
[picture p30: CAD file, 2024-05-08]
3DPrinting/方案一（含米家拓展）/外壳主体.STL
111.0 x 38.8 x 48.0

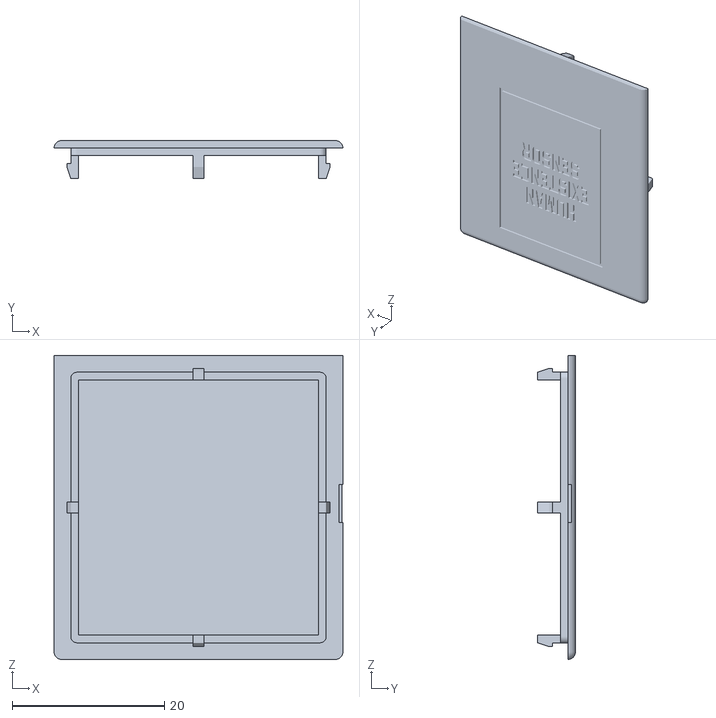
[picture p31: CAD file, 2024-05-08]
3DPrinting/方案二（含米家拓展）/米家拓展盖板.STL
38.0 x 5.00 x 40.0

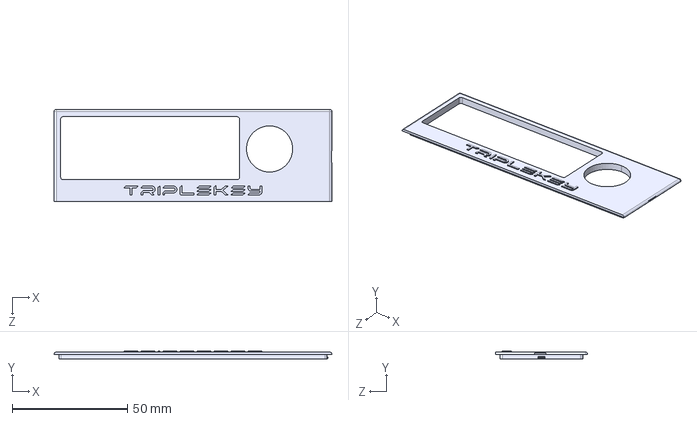
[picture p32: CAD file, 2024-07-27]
3DPrinting/新方案三（★★★推荐★★★）/改进版新方案FDM（适用拓竹等常见打印机）/主体盖板FDM.STEP
120.5 x 3.40 x 40.0 mm

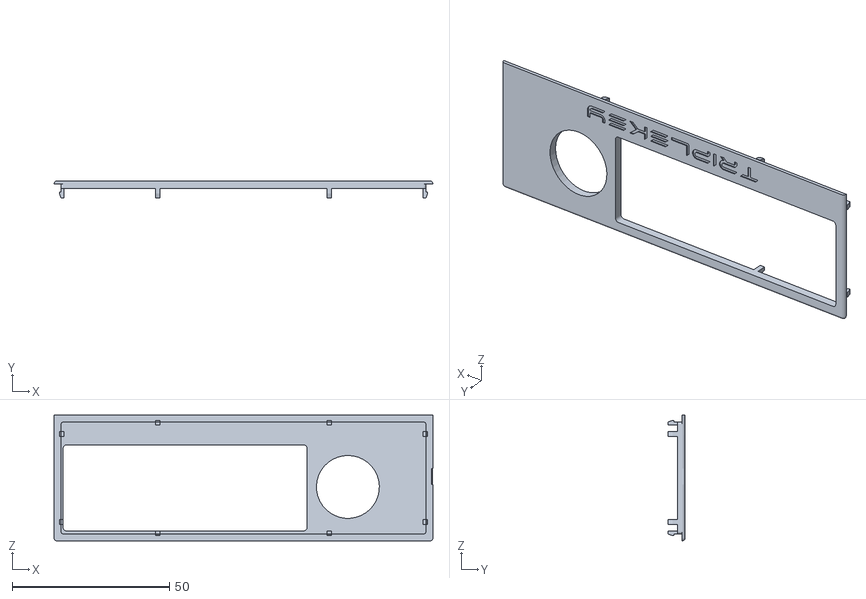
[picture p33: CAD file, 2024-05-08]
3DPrinting/新方案三（★★★推荐★★★）/改进版新方案SLA光固化（适用嘉立创3D打印）/主体盖板.STL
120.5 x 5.50 x 40.0

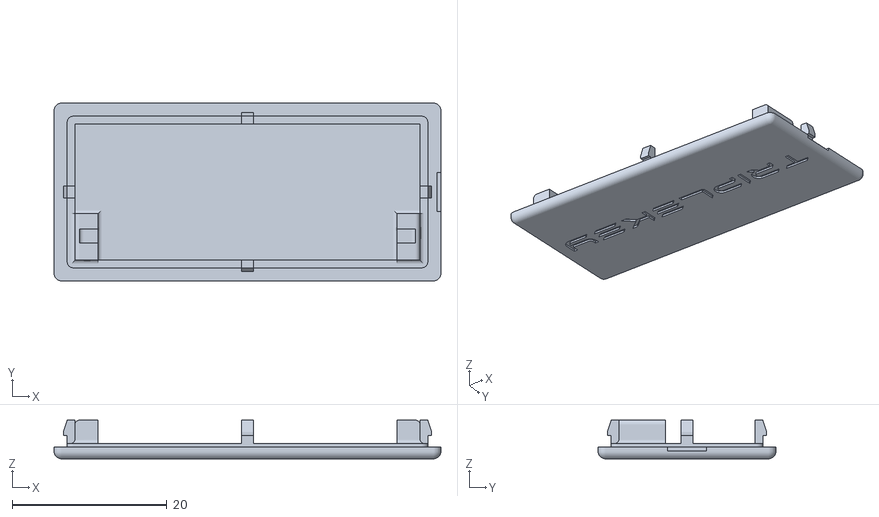
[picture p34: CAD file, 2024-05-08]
3DPrinting/方案一（含米家拓展）/米家拓展盖板.STL
50.0 x 23.0 x 5.00

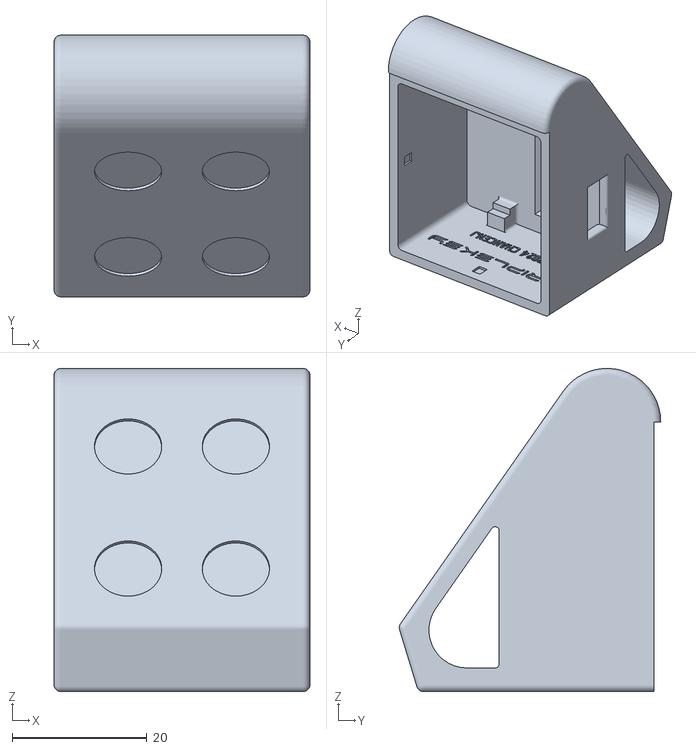
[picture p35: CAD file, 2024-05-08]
3DPrinting/方案二（含米家拓展）/米家拓展外壳.STL
38.0 x 38.8 x 48.0

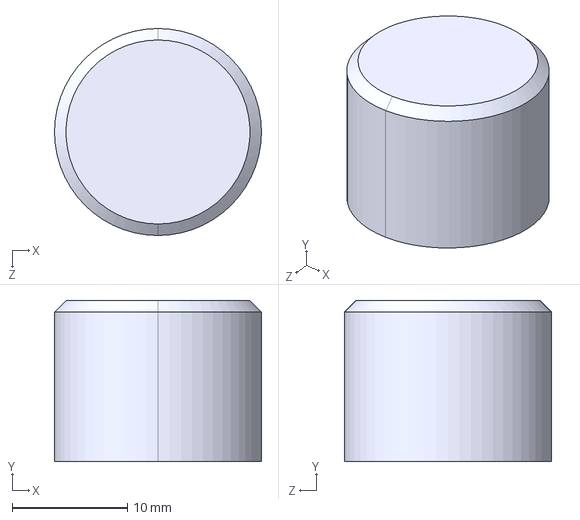
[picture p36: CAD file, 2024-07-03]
3DPrinting/新方案三（★★★推荐★★★）/改进版新方案FDM（适用拓竹等常见打印机）/旋钮FDM.STEP
18.0 x 14.0 x 18.0 mm

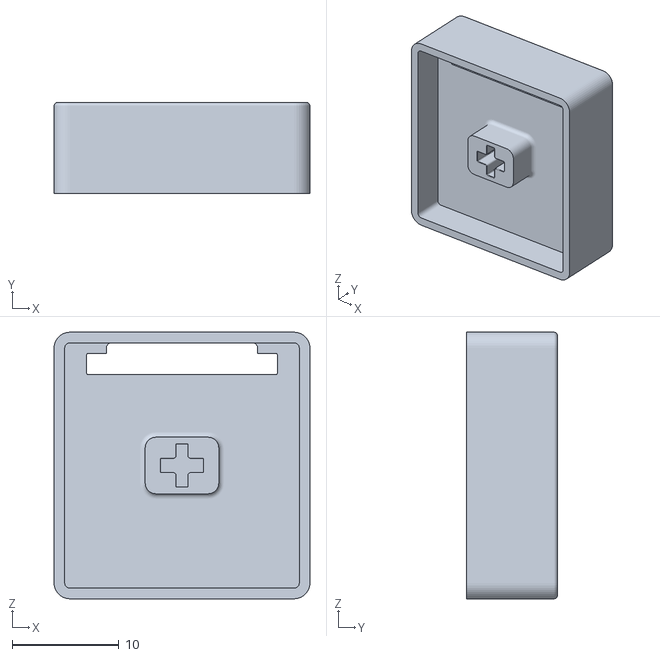
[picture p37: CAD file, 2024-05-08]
3DPrinting/新方案三（★★★推荐★★★）/改进版新方案SLA光固化（适用嘉立创3D打印）/屏幕按键外壳x3.STL
24.0 x 8.55 x 25.0

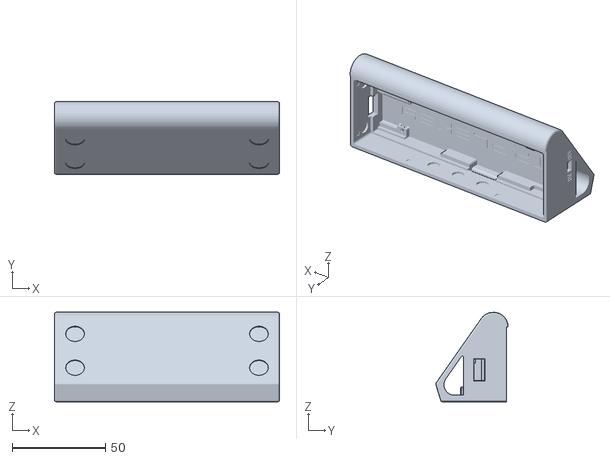
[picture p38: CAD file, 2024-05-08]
3DPrinting/方案二（含米家拓展）/主体外壳.STL
120.5 x 38.8 x 48.0

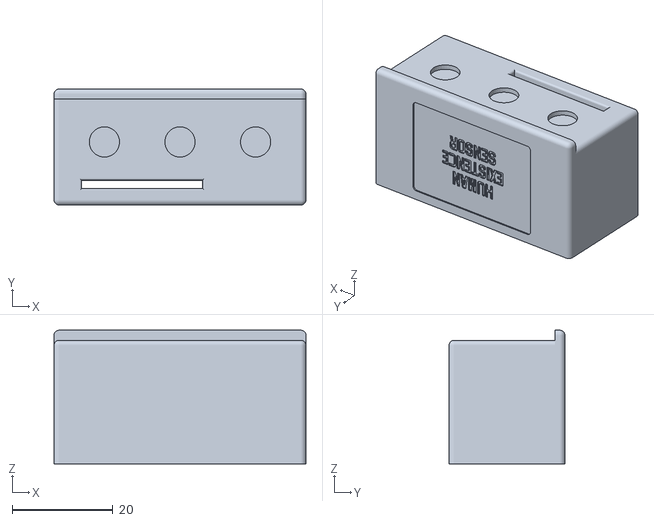
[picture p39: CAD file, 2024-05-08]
3DPrinting/方案一（含米家拓展）/米家拓展外壳.STL
50.0 x 23.0 x 26.5

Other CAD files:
3DPrinting/新方案三（★★★推荐★★★）/改进版新方案FDM（适用拓竹等常见打印机）/主体外壳FDM.STEP
3DPrinting/新方案三（★★★推荐★★★）/改进版新方案SLA光固化（适用嘉立创3D打印）/旋钮.STL
3DPrinting/新方案三（★★★推荐★★★）/改进版新方案FDM（适用拓竹等常见打印机）/按键屏幕FDM.STEP

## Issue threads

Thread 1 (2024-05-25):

请根据cc BY-NC-SA协议，修改说辞，不要让人误以为是自创的

MakerM0, 2024-05-25:
首先，非常感谢你对[3plus](https://oshwhub.com/kakaka/Multi-function-macro-keyboard-3Plus20-version)项目的喜爱，

但是，还请遵守原项目开源协议，[署名-非商业性使用-相同方式共享 4.0 国际 (CC BY-NC-SA 4.0)](https://creativecommons.org/licenses/by-nc-sa/4.0/legalcode.zh-Hans)
请给出具体源地址和作者署名，以及修改之处；[https://github.com/MakerM0/3Plus_v2](https://github.com/MakerM0/3Plus_v2)
对于衍生的项目，功能方面的请不要写成重构，毕竟里面的基础框架还是用的我的，请尊重我的劳动成功（毕竟花了大量时间写的）
硬件部分，也是如此，旋钮和按键模型也是用的本人的，或者衍生出来的，主板pcb，框架也无大的改变，除了更改了部分元件和位置

共同维护开源环境，期待你的回复

ChancenJ, 2024-05-25:
已更新项目文档

MakerM0, 2024-05-25:
感谢修正，欢迎一同学习进步交流

Closed 2024-05-25.

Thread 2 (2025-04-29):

编译出现找不到num_fbs，bits_per_pixel，esp_lcd_rgb_panel_get_frame_buffer的错误

whwxxstsyd, 2025-04-29:
请问大佬，您使用的arduino_esp32的版本是什么，我安装的是最新的6.10.0，但是在编译的时候会出现提示找不到num_fbs，bits_per_pixel，esp_lcd_rgb_panel_get_frame_buffer的错误，目测好像是版本的问题，6.10.0使用的应该还是基于idf4.x，而需要的库函数中则有调用到idf5.x的内容，请问大佬是如何解决的，十分感谢

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

ChancenJ, 2025-04-29:
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

时间久远，我只知道版本6.6.0了，怎么操作我已经忘了，应该pio那个管理页面里能改platform的版本吧

ChancenJ, 2025-04-29:
没有动过底层的，我看了我的文件夹里压根没有bb_spi_lcd这个东西，我也不知道怎么出现的，也许得把6.10.0删干净了重装

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

whwxxstsyd, 2025-04-30:
感谢大神的回复，目前已经发现原因了，是库版本的问题，可能您那个时候使用的PNGdec和JPEGdec这两个库在当时作者是基于idf4.x版本开发的，而到我目前编写回复的时间点，作者使用的PNGdec1.1.3和JPEGDEC1.8.1则是基于idf5.x开发的，所以直接包含使用的话会出现上面我所给出的错误。目前解决方案是修改TripleKey项目里面platformIO.ini文件中的lib_deps =内容，去掉其中的^符号（提示：在 Arduino 库的版本号前面的 ^ 是语义化版本控制中用于依赖管理的一种版本范围指定符号，^ 符号表示在更新依赖库时，允许更新到不改变主版本号的最新版本。也就是说，只要主版本号保持不变，次版本号和修订号可以更新到最新），使版本和作者当时的开发环境对齐，目前已经可以编译通过，望后面复刻，碰到相同问题的朋友做参考。再次感谢大神的回复。

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

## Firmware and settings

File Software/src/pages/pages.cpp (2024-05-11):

#include "pages.h"
#include "manager/manager.h"
#include "board_def.h"
#include "app/app_key.h"
#include "app/app_timeout.h"


#include "pages/shortcut/shortcut.h"
#include "pages/clock/clock.h"
#include "pages/media/media.h"
#include "pages/web/web.h"
#include "pages/pcstate/pcstate.h"
#include "pages/weather/weather.h"
#include "pages/pomodoro/pomodoro.h"
#include "pages/keyboard/keyboard.h"
#include "pages/bilibili/bilibili.h"
#include "pages/stocks/stocks.h"
#include "pages/mijia/mijia.h"
#include "pages/settings/settings.h"
#include "pages/photo/photo.h"
#include "pages/countdown/countdown.h"

//需要添加自己的功能页面
page_t *pages[] = {
    &page_main,
    &page_clock,
    &page_weather,
    &page_stocks,
    &page_mijia,
    &page_photo,
    // &page_pcstate,
    &page_keyboard,
    &page_shortcut,
    &page_web,
    &page_media,
    &page_bilibili,
    &page_countdown,
    &page_pomodoro,
    &page_settings,
    
    
};

static const uint8_t pages_num = ARRAY_SIZE(pages);
static int16_t row_index = 0;
static int16_t row_num;
static int16_t page_index = 1;
// static uint8_t page_old = 1;

static uint32_t cnt = 0;
// static char *buffer;
static uint8_t key_type;
static void init(void *data)
{

    manager.index = 0;
    row_num = ((pages_num - 1) % 3) ? ((pages_num - 1) / 3 + 1) : ((pages_num - 1) / 3);
}

static void enter(void *data)
{
    Serial.printf("enter:%d  ", page_index);
    row_index = page_index / 3;
    page_index = row_index * 3 + 1;
    Serial.printf("then:%d\r\n", page_index);
    uint16_t width = pages[page_index]->icon_width;
    uint16_t height = pages[page_index]->icon_height;

    int16_t x1;
	int16_t y1;
	uint16_t w;
	uint16_t h;

    gfx1->fillScreen(BLACK);
    gfx2->fillScreen(BLACK);
    gfx3->fillScreen(BLACK);

    gfx1->setTextSize(1);
    gfx2->setTextSize(1);
    gfx3->setTextSize(1);

    gfx1->setUTF8Print(true);
	gfx2->setUTF8Print(true);
	gfx3->setUTF8Print(true);



    for (uint8_t i = 0; i < 3; i++)
    {
        if ((i + page_index) < pages_num)
        {
            gfx[i]->setCursor(0, 40+32);
            gfx[i]->setTextColor(QINGSHUILAN);
            gfx[i]->setFont(u8g2_font_maniac_tr);
            gfx[i]->printf("%d\r\n", page_index + i);

            gfx[i]->setFont(Guangliang_Title_26);
            gfx[i]->getTextBounds(pages[page_index + i]->title_cn, 0, 0, &x1, &y1, &w, &h);
	        gfx[i]->setCursor((OLED_WIDTH - w) / 2, 108);
            gfx[i]->printf("%s", pages[page_index + i]->title_cn);
            gfx[i]->drawXBitmap(40, 0+32, pages[page_index + i]->icon, pages[page_index + i]->icon_width, pages[page_index + i]->icon_height, random(0xffff));
        }
    }

    delay(200);

    app_key_clean();

    manager_setBusy(false);
}

static void switchevent()
{
    

    page_index = row_index * 3 + 1;
    // Serial.printf("switchevent: row_num %d    row_index %d    page_index %d\r\n", row_num, row_index, page_index);
    uint16_t width = pages[page_index]->icon_width;
    uint16_t height = pages[page_index]->icon_height;

    int16_t x1;
	int16_t y1;
	uint16_t w;
	uint16_t h;

    gfx1->fillScreen(BLACK);
    gfx2->fillScreen(BLACK);
    gfx3->fillScreen(BLACK);

    gfx1->setUTF8Print(true);
	gfx2->setUTF8Print(true);
	gfx3->setUTF8Print(true);

    for (uint8_t i = 0; i < 3; i++)
    {
        if ((i + page_index) < pages_num)
        {
            gfx[i]->setCursor(5, 40+32);
            gfx[i]->setTextColor(QINGSHUILAN);
            gfx[i]->setFont(u8g2_font_maniac_tr);
            gfx[i]->printf("%d\r\n", page_index + i);

             
            gfx[i]->setFont(Guangliang_Title_26);
            gfx[i]->getTextBounds(pages[page_index + i]->title_cn, 0, 0, &x1, &y1, &w, &h);
	        gfx[i]->setCursor((OLED_WIDTH - w) / 2, 108);
            gfx[i]->printf("%s", pages[page_index + i]->title_cn);
            gfx[i]->drawXBitmap(40, 0+32, pages[page_index + i]->icon, pages[page_index + i]->icon_width, pages[page_index + i]->icon_height, random(0xffff));
        }
    }
}

static void switchNext()
{
    row_index++;
    if (row_index == row_num)
    {
        row_index = 0;
    }
}

static void switchPrev()
{

    row_index--;
    if (row_index < 0)
        row_index = row_num - 1;
}

static void loop(void *data)
{

    KEY_TYPE key = app_key_get();
    switch (key)
    {
    case KEY1_DOWN:
        app_led_set(LED1, app_led_color(random(10, 255), random(10, 255), random(10, 255)));
		app_led_update();
        break;
    case KEY1_SHORT:
        app_led_off();
        manager.index = page_index;
        Serial.println(manager.index);
        manager_switchToChild(); //进入子项目
        break;
    case KEY2_DOWN:
        app_led_set(LED2, app_led_color(random(10, 255), random(10, 255), random(10, 255)));
		app_led_update();
        break;
    case KEY2_SHORT:
        app_led_off();
        if ((page_index + 1) < pages_num)
        {
            manager.index = page_index + 1;
            Serial.println(manager.index);
            manager_switchToChild(); //进入子项目
        }
        break;
    case KEY3_DOWN:
        app_led_set(LED3, app_led_color(random(10, 255), random(10, 255), random(10, 255)));
		app_led_update();
        break;
    case KEY3_SHORT:
        app_led_off();
        if ((page_index + 2) < pages_num)
        {
            manager.index = page_index + 2;
            Serial.println(manager.index);
            manager_switchToChild(); //进入子项目
        }
        break;

    case KEY1_UP:
    case KEY2_UP:
    case KEY3_UP:
        app_led_off();
        break;

    case ENC_NEXT:
        switchNext();
        switchevent();
        break;
    case ENC_PREV:
        switchPrev();
        switchevent();
        break;
    default:
        break;
    }
}

static void exit(void *data)
{

    manager_setBusy(true);

    // free(buffer);
}

page_t page_main = {
    .init = init,
    .enter = enter,
    .exit = exit,
    .loop = loop,
    .title_en = "main",
    .title_cn = "主页",
    .icon = NULL,
    .icon_width = 0,
    .icon_height = 0,
    .sleep_enable = true,
    .wakeup_btn_effect_enable = false,
    .acc_enable = true,

};

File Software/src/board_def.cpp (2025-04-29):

#include "board_def.h"
#include <ESPAsyncWebServer.h>
#include <ElegantOTA.h>

WiFiManager wm;
AsyncWebServer server(80);

char stored_weather_key[40];
char stored_weather_city[40];
char stored_weather_apihost[40];
std::vector<StockInfo> stocks;
std::vector<MijiaSwitch> sws;
std::vector<std::vector<String>> webstring;
uint8_t rotary = 4;       // 旋转编码器限位值（2或4）
bool enc_reverse = false; // 旋转编码器是否反向

BleKeyboard bleKeyboard("TripleKey", "ChancenJ", 100);

DFRobot_CH423 ch423;

String NewVersion = "NA";

// flag for saving data
bool shouldSaveConfig = false;

// callback notifying us of the need to save config
void saveConfigCallback()
{
    Serial.println("Should save config");
    shouldSaveConfig = true;
}

struct tm timeInfo;

Button2 button1, button2, button3, button4;

// Change these two numbers to the pins connected to your encoder.
//   Best Performance: both pins have interrupt capability
//   Good Performance: only the first pin has interrupt capability
//   Low Performance:  neither pin has interrupt capability
Encoder myEnc(PIN_EC_A, PIN_EC_B);

int rst = PIN_RST;
int backlight = PIN_BL;

int mosi = PIN_MOSI;
int sclk = PIN_SCLK;
int dc = PIN_DC;

int cs1 = PIN_CS1;
int cs2 = PIN_CS2;
int cs3 = PIN_CS3;

/* More data bus class: https://github.com/moononournation/Arduino_GFX/wiki/Data-Bus-Class */
Arduino_DataBus *bus1 = new Arduino_ESP32SPI(dc /*dc*/, cs1 /*cs*/, sclk /*sclk*/, mosi /*mosi*/);
// Arduino_DataBus *bus1 = new Arduino_SWSPI(dc /*dc*/, cs1 /*cs*/, sclk /*sclk*/, mosi /*mosi*/,GFX_NOT_DEFINED /*miso*/);
Arduino_DataBus *bus2 = new Arduino_ESP32SPI(dc /*dc*/, cs2 /*cs*/, sclk /*sclk*/, mosi /*mosi*/);
// Arduino_DataBus *bus2 = new Arduino_SWSPI(dc /*dc*/, cs2 /*cs*/, sclk /*sclk*/, mosi /*mosi*/,GFX_NOT_DEFINED /*miso*/);
Arduino_DataBus *bus3 = new Arduino_ESP32SPI(dc /*dc*/, cs3 /*cs*/, sclk /*sclk*/, mosi /*mosi*/);
// Arduino_DataBus *bus3 = new Arduino_SWSPI(dc /*dc*/, cs3 /*cs*/, sclk /*sclk*/, mosi /*mosi*/,GFX_NOT_DEFINED /*miso*/);

/* More display class: https://github.com/moononournation/Arduino_GFX/wiki/Display-Class */
#ifdef SCREEN_NV3023
Arduino_GFX *gfx1 = new Arduino_NV3023(bus1, -1, 2 /* rotation */, false, 128, 128);
Arduino_GFX *gfx2 = new Arduino_NV3023(bus2, -1, 2 /* rotation */, false, 128, 128);
Arduino_GFX *gfx3 = new Arduino_NV3023(bus3, -1, 2 /* rotation */, false, 128, 128);
#endif
#ifdef SCREEN_GC9107
Arduino_GFX *gfx1 = new Arduino_GC9107(bus1, -1, 0 /* rotation */, true, 128, 128);
Arduino_GFX *gfx2 = new Arduino_GC9107(bus2, -1, 0 /* rotation */, true, 128, 128);
Arduino_GFX *gfx3 = new Arduino_GC9107(bus3, -1, 0 /* rotation */, true, 128, 128);
#endif

/*******************************************************************************
 * End of Arduino_GFX setting
 ******************************************************************************/

Arduino_GFX *gfx[3] = {gfx1, gfx2, gfx3};

uint8_t HumanState;
uint8_t WireErr;

void configModeCallback(WiFiManager *myWiFiManager)
{
    gfx2->setTextColor(RED);
    gfx2->println("进入配置模式");
    gfx2->print("请连接热点");
    gfx2->println(myWiFiManager->getConfigPortalSSID());
    gfx2->print("进入");
    gfx2->println(WiFi.softAPIP());
    gfx2->setTextColor(QINGSHUILAN);
}

void audio_poweroff()
{
    pinMode(PIN_AUDIO_SD, OUTPUT);
    digitalWrite(PIN_AUDIO_SD, LOW);
}

void audio_poweron()
{
    pinMode(PIN_AUDIO_SD, OUTPUT);
    digitalWrite(PIN_AUDIO_SD, HIGH);
}

unsigned long ota_progress_millis = 0;

void onOTAStart()
{
    // Log when OTA has started
    Serial.println("OTA update started!");
    gfx3->setCursor(38, 100);
    gfx3->setFont(&GillSansEN_Bold_12);
    gfx3->setTextColor(GREEN, BLACK);
    gfx3->print("START");
    gfx3->drawRoundRect(12, 105, 104, 10, 5, ORANGE);
    gfx3->fillRoundRect(14, 107, 100, 6, 3, BLACK);

    // <Add your own code here>
}

void onOTAProgress(size_t current, size_t final)
{
    // Log every 1 second
    if (millis() - ota_progress_millis > 1000)
    {
        ota_progress_millis = millis();
        Serial.printf("OTA Progress Current: %u bytes, Final: %u bytes\n", current, final);
        gfx3->setCursor(38, 100);
        gfx3->setFont(&GillSansEN_Bold_12);
        gfx3->setTextColor(ORANGE, BLACK);
        gfx3->printf(" %03d %%  ", current * 100 / final);
        gfx3->drawRoundRect(12, 105, 104, 10, 5, ORANGE);
        gfx3->fillRoundRect(14, 107, current * 100 / final, 6, 3, ORANGE);
    }
}
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

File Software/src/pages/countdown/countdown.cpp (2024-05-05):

#include "countdown.h" //修改
#include "board_def.h"
#include "app/app_key.h"
#include "app/app_audio.h"

typedef enum
{
	SET,
	RUNNING,
	PAUSE,
} Mode;

static Mode mode = SET;
static uint8_t set;

static bool flicker;

static int8_t settime[3] = {0, 5, 0};
static int8_t nowtime[3] = {0, 5, 0};

static unsigned long lastFlickerTime;
static unsigned long lastCountdownTime;
static unsigned long lastBarUpdateTime;
static unsigned long StartTime;
static unsigned long PauseTime;
static unsigned long ContinueTime;
static long spendms = 0;

void dispSetNum(uint8_t set)
{
	gfx[set]->setCursor(5, 90);
	gfx[set]->printf("%02d", settime[set]);
}
void dispNowNum(uint8_t set)
{
	gfx[set]->fillRect(0, 10, 112, 108, BLACK);
	gfx[set]->setCursor(5, 90);
	gfx[set]->printf("%02d", nowtime[set]);
}

void dispHMS()
{
	for (int i = 0; i < 3; i++)
	{
		gfx[i]->setFont(&GillSansEN_Bold_12);
		gfx[i]->setCursor(112, 90);
	}
	gfx[0]->print("h");
	gfx[1]->print("m");
	gfx[2]->print("s");
	for (int i = 0; i < 3; i++)
	{
		gfx[i]->setFont(&MiSans_Regular45pt_number);
	}
}

void CountDown()
{
	if (millis() - lastCountdownTime >= 1000)
	{
		lastCountdownTime = millis();
		nowtime[2]--;
		if (nowtime[2] >= 0)
		{
			dispNowNum(2);
		}
		else
		{
			nowtime[1]--;
			nowtime[2] = 59;
			if (nowtime[1] >= 0)
			{
				dispNowNum(2);
				dispNowNum(1);
			}
			else
			{
				nowtime[0]--;
				nowtime[1] = 59;
				if (nowtime[0] >= 0)
				{
					dispNowNum(2);
					dispNowNum(1);
					dispNowNum(0);
				}
				else
				{
					mode = PAUSE;
					for (int i = 0; i < 3; i++)
					{
						gfx[i]->setTextColor(RED);
						nowtime[i] = 0;
						dispNowNum(i);
						app_led_set(i, app_led_color(0x70, 0x00, 0x00));
						app_led_update();
					}
					dispHMS();
					app_audio_play_wav("/end.wav");
				}
			}
		}
	}
}

void SetFlicker()
{
	if (millis() - lastFlickerTime >= 500)
	{
		lastFlickerTime = millis();
		if (flicker)
		{
			gfx[set]->fillRect(0, 10, 112, 108, BLACK);
		}
		else
		{
			dispSetNum(set);
		}
		flicker = !flicker;
		
	}
}

void dispProgressBar()
{
	unsigned long setms = (settime[0] * 3600 + settime[1] * 60 + settime[2]) * 1000;
	float ratio = (float)setms / spendms;
	uint16_t barlength = ceil(128 * 3 / ratio);
	if (barlength <= 128)
	{
		gfx[2]->fillRect(128 - barlength, 118, barlength, 10, BLACK);
	}
	else if (barlength <= 256)
	{
		gfx[2]->fillRect(0, 118, 128, 10, BLACK);
		gfx[1]->fillRect(256 - barlength, 118, barlength - 128, 10, BLACK);
	}
	else
	{
		gfx[2]->fillRect(0, 118, 128, 10, BLACK);
		gfx[1]->fillRect(0, 118, 128, 10, BLACK);
		gfx[0]->fillRect(384 - barlength, 118, barlength - 256, 10, BLACK);
	}
}

static void init(void *data)
{
	set = 2;
	flicker = true;
}

static void enter(void *data)
{
	// insert code
	if (mode == SET)
	{
		for (int i = 0; i < 3; i++)
		{
			gfx[i]->fillScreen(BLACK);
			gfx[i]->setFont(&MiSans_Regular45pt_number);
			gfx[i]->setTextColor(JINZI);
			dispSetNum(i);
		}
		dispHMS();
	}
	else if (mode == PAUSE)
	{
		for (int i = 0; i < 3; i++)
		{
			gfx[i]->fillScreen(BLACK);
			gfx[i]->setFont(&MiSans_Regular45pt_number);
			gfx[i]->setTextColor(ORANGE);
			dispNowNum(i);
			gfx[i]->fillRect(0, 118, 128, 10, ORANGE);
			app_led_set(i, app_led_color(255, 220, 0));
			app_led_update();
		}
		dispProgressBar();
		dispHMS();
	}
	else
	{
		unsigned long spendsec = (millis() - lastCountdownTime) / 1000;
		Serial.printf("页面外消耗时间：%ds\n", spendsec);
		unsigned long remainsec = nowtime[0] * 3600 + nowtime[1] * 60 + nowtime[2];
		Serial.printf("退出前剩余时间：%ds\n", remainsec);
		if (spendsec < remainsec)
		{
			remainsec -= spendsec;
			nowtime[0] = remainsec / 3600;
			remainsec -= nowtime[0] * 3600;
			nowtime[1] = remainsec / 60;
			remainsec -= nowtime[1] * 60;
			nowtime[2] = remainsec;
		}
		else
		{
			nowtime[0] = 0;
			nowtime[1] = 0;
			nowtime[2] = 0;
		}
		lastCountdownTime = millis();
		for (int i = 0; i < 3; i++)
		{
			gfx[i]->fillScreen(BLACK);
			gfx[i]->setFont(&MiSans_Regular45pt_number);
			gfx[i]->setTextColor(JINZI);
			dispNowNum(i);
			gfx[i]->fillRect(0, 118, 128, 10, ORANGE);
		}
		dispHMS();
	}
	lastFlickerTime = millis();
	//
	manager_setBusy(false);
}

static void loop(void *data)
{
	if (mode == SET)
	{
		SetFlicker();
	}
	if (mode == RUNNING)
	{
		CountDown();
		if (millis() - lastBarUpdateTime >= 100)
		{
			spendms += millis() - lastBarUpdateTime;
			lastBarUpdateTime = millis();
			dispProgressBar();
		}
	}
	KEY_TYPE key;
	key = app_key_get();
	switch (key)
	{

	case KEY1_DOWN:
		if (mode == SET)
		{
			dispSetNum(set);
			set = 0;
		}

		break;
	case KEY2_DOWN:
		if (mode == SET)
		{
			dispSetNum(set);
			set = 1;
		}
		break;
	case KEY3_DOWN:
		if (mode == SET)
		{
			dispSetNum(set);
			set = 2;
		}
		break;
	case KEY4_SHORT:
		if (mode == SET)
		{
			for (int i = 0; i < 3; i++)
			{
				nowtime[i] = settime[i];
				dispNowNum(i);
				gfx[i]->fillRect(0, 118, 128, 10, ORANGE);
			}
			lastCountdownTime = millis();
			lastBarUpdateTime = millis();
			StartTime = millis();
			spendms = 0;
			mode = RUNNING;
			Serial.println("开始");
		}
		else if (mode == RUNNING)
		{
			mode = PAUSE;
			PauseTime = millis();
			Serial.println("暂停");
			for (int i = 0; i < 3; i++)
			{
				gfx[i]->setTextColor(ORANGE);
				dispNowNum(i);
				app_led_set(i, app_led_color(255, 220, 0));
				app_led_update();
			}
			dispHMS();
		}
		else
		{
			mode = RUNNING;
			ContinueTime = millis();
			spendms -= ContinueTime - PauseTime;
			Serial.println("继续");
			for (int i = 0; i < 3; i++)
			{
				gfx[i]->setTextColor(JINZI);
				dispNowNum(i);
			}
			dispHMS();
			app_led_off();
		}
		break;
	case KEY4_DOUBLE:
		if (mode == RUNNING || mode == PAUSE)
		{
			mode = SET;
			Serial.println("终止");
			for (int i = 0; i < 3; i++)
			{
				gfx[i]->fillRect(0, 10, 112, 108, BLACK);
				gfx[i]->setTextColor(JINZI);
				dispSetNum(i);
				gfx[i]->fillRect(0, 118, 128, 10, ORANGE);
			}
			dispHMS();
			lastFlickerTime = millis();
			app_led_off();
		}
		break;
	case ENC_NEXT:
		settime[set]++;
		if (settime[set] >= 60)
		{
			settime[set] = 0;
		}
		break;
	case ENC_PREV:
		settime[set]--;
		if (settime[set] < 0)
		{
			settime[set] = 59;
		}
		break;

	case KEY4_LONG: // 长按
		app_led_off();
		manager_switchToParent(); // 进入父项目 //退出
		break;
	default:
		break;
	}
}

static void exit(void *data)
{
	// insert code

	//
	manager_setBusy(true);
}

#include "img.h"
page_t page_countdown = {
	.init = init,
	.enter = enter,
	.exit = exit,
	.loop = loop,
	.title_en = "countdown",
	.title_cn = "倒计时",
	.icon = img_bits,
	.icon_width = img_width,
	.icon_height = img_height,
	.sleep_enable = false,
	.wakeup_btn_effect_enable = false,
	.acc_enable = false,

};

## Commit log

2024-03-22 更新开发计划
2024-03-22 更改初始版本号
2024-03-24 V0.0.2 更换主页字体为MiSans，颜色为清水蓝；页面标题统一首字母大写。
2024-03-24 V0.0.3 增加WS2812 RGB LED灯控制基本代码；增加启动时LED灯点亮；
2024-03-24 V0.0.4 番茄钟增加LED；
2024-03-24 V0.0.5 预控股票代码结构
2024-03-24 V0.0.6 键盘增加LED；
2024-03-24 V0.0.7 主页增加LED；
2024-03-24 V0.0.8 多媒体增加LED；时间页短按KEY1不再报时，避免主页进入时间页检测到短按报时
2024-03-24 V0.0.9 多媒体图标居中；
2024-03-24 V0.0.10 米家无线开关代码框架
2024-03-24 V0.0.11 优化主页按键检测逻辑
2024-03-25 V0.0.12 优化米家
2024-03-25 V0.0.13 增加米家功能复用函数
2024-03-25 V0.0.14 米家开关全新框架，统一按键结构体，加快响应速度，米家页旋钮转动变为转一次移动一格
2024-03-25 V0.0.15 米家长按换用非阻塞方式（无效果，可能需要多线程）
2024-03-25 更改版本号
2024-03-25 V0.0.15 米家全开关测试
2024-03-25 V0.0.16 实时股票功能基本实现（暂无UI）
2024-03-25 V0.0.17 主页更换中文显示；股票页完善，显示中文
2024-03-25 V0.0.18 更换米家引脚
2024-03-25 V0.0.19 更改页面顺序；添加米家图标
2024-03-25 V0.1.0 增加实时股票功能，股票页显示当前时间、股票名称、当前价格、涨跌幅，每2分钟更新一次，股票页每10秒自动切换，旋钮可手动切换。
2024-03-25 V0.1.0 更新说明
2024-03-25 V0.1.1 增加LED亮度调节功能；股票页增加红绿呼吸灯，上涨为红，下跌为绿
2024-03-25 V0.0.1 更新日志
2024-03-26 V0.1.2 优化股票页时间显示
2024-03-26 V0.1.3 实时股票功能完全实现；股票页显示日期、星期、时间；股票页增加icon；
2024-03-26 V0.1.4 删除部分时钟图片
2024-03-26 V0.1.5 修复LED亮度问题
2024-03-26 V0.1.6 优化股票功能
2024-03-26 V0.1.7 标注页面模板修改处
2024-03-26 V0.1.8 新天气代码初步框架
2024-03-27 V0.1.9 优化股票
2024-03-27 V0.1.10 全新天气代码框架，接入和风天气API
2024-03-27 V0.0.11 天气UI测试
2024-03-28 V0.1.12 更换启动页面
2024-03-28 V0.1.13 更新Arduino_GFX_1.4.6
2024-03-28 V0.1.14 更换部分icon
2024-03-28 V0.1.15 优化天气UI；统一天气参数类型
2024-03-28 V0.1.16 完善天气获取，可通过Wifi配置城市和密钥
2024-03-28 V0.1.17 增加“正在查询”提示
2024-03-28 V0.1.18 多媒体页旋钮逻辑更改，左旋降低音量，右旋升高音量
2024-03-28 V0.1.19 增加居中显示PNG函数；Web页图标居中；修改快捷Web网址
2024-03-28 V0.1.20 哔哩哔哩增加旋钮调节音量
2024-03-28 V0.1.21 增加天气显示项目；修改页面顺序
2024-03-29 V0.1.22 更新天气UI，增加显示项目，优化天气获取逻辑
2024-03-29 V0.1.23 “正在查询”提示可选择屏幕
2024-03-29 V0.2.0 重构天气功能，采用和风天气API，天气页显示当前温度、相对湿度、空气质量、天气状况、风向风力、最高最低温度、日出日落时间，旋钮可切换显示三天天气预报。
2024-03-29 V0.2.1 换用函数指针来使天气页显示不同内容
2024-03-29 V0.2.2 优化天气UI
2024-03-30 V0.2.3 启用I2C控制米家，采用PCF8574芯片，通过2个引脚控制8个开关
2024-03-30 V0.2.4 修复股票页星期bug
2024-03-30 V0.2.5 米家增加读取状态
2024-03-30 V0.2.6 完善米家读取状态
2024-03-31 V0.2.7 更改I2C引脚
2024-04-01 V0.2.8 优化配置文件相关
2024-04-01 V0.2.9 增加米家开关图标，同步开关状态
2024-04-01 V0.2.10 增大启动页配置字体
2024-04-01 V0.2.11 增加快捷切换页面函数；时间页KEY1双击快捷跳转天气
2024-04-01 V0.2.11 增加快捷切换页面函数；时间页KEY1双击快捷跳转天气，KEY1长按跳转米家
2024-04-02 V0.2.12 增加Web服务器框架，将用于配置股票、米家、天气等
2024-04-04 V0.2.13 增加I2C芯片CH423S代码框架
2024-04-06 V0.2.14 米家开关控制初步支持CH423S，暂无读取状态
2024-04-06 V0.2.15 米家开关支持CH423S读取状态
2024-04-06 V0.2.16 大幅修改米家代码框架，增加人在传感器代码框架，两者结合
2024-04-06 V0.2.17 米家页增加快速返回时钟（旋钮单击）
2024-04-09 V0.2.18 米家代码优化；增加人在传感器与米家KEY1绑定状态
2024-04-09 V0.2.19 优化人在传感器
2024-04-09 V0.3.0 增加米家无线开关，可接入米家控制米家设备；增加人体存在传感器，接入米家可设置智能场景联动设备。
2024-04-10 V0.3.1 修复一些bug；快捷键增加显示桌面
2024-04-10 V0.3.2 修复遗漏字体文件
2024-04-10 V0.3.3 新增几个快捷键；更换快捷键图标
2024-04-10 config文件开发中预配置
2024-04-10 V0.3.4 倒计时页面预留
2024-04-10 V0.3.5 快捷键增加LED
2024-04-10 V0.3.6 快捷键页面更换字体
2024-04-10 V0.3.7 调整B站页面图标位置
2024-04-11 V0.3.8 增加根据有人无人状态自动开关屏幕和LED灯功能
2024-04-11 V0.3.9 优化人在传感器
2024-04-11 V0.3.10 Web设置框架，用于配置股票、网页、米家
    [config_stocks.txt]
2024-04-11 V0.3.11 Web页增加米家配置，保存按钮换行
    [config_mijia.txt]
2024-04-12 V0.3.12 无人时关闭屏幕背光
2024-04-12 V0.3.13 完善设置框架
2024-04-12 V0.3.14 股票、米家初步支持Web页进行配置；修复一些bug
    [config_mijia.txt, config_stocks.txt]
2024-04-12 V0.3.15 优化设置页；更换主页字体；增加设置icon
2024-04-12 V0.3.16 多媒体、哔哩哔哩增加短按旋钮静音
2024-04-12 V0.3.17 优化浏览器打开
2024-04-12 V0.3.18 设置页增加二维码，扫码配置
2024-04-13 V0.3.19 完善设置页信息
2024-04-13 V0.3.20 修改页面顺序；修改多媒体、快捷键icon；优化PNG读取代码
2024-04-13 V0.3.21 优化代码
2024-04-14 V0.3.22 将HTML存储到文件，运行时再读取HTML
2024-04-16 V0.3.23 增加图片上传Web页（无上传功能）
2024-04-16 V0.3.24 实现网页图标上传功能
2024-04-16 V0.3.25 天气查询过程显示城市名称和代码
2024-04-16 V0.3.26 Web配置页增加天气配置
2024-04-17 V0.3.27 修复天气城市字体
2024-04-17 V0.3.28 实现快捷网页配置功能；优化配置页面
    [config_web.txt]
2024-04-17 V0.3.29 配置页增加网页图标上传/删除功能； 配置页增加显示文件列表按钮
2024-04-18 V0.4.0 增加自定义配置功能，可对天气、股票、米家、快捷网页进行自定义配置。
2024-04-18 V0.4.1 更换多媒体控件图标
2024-04-18 V0.4.2 删除旧天气代码
2024-04-18 V0.4.3 增加更多设置页面；增加整点报时设置可选项
2024-04-18 修改更新日志
2024-04-19 V0.4.4 重构时钟主题切换代码；增加时钟主题自动切换可选项
2024-04-19 V0.4.5 修复快捷进入配置页导致重启的BUG
    [config_mijia.txt, config_web.txt]
2024-04-20 V0.4.6 B站页图标居中，增加LED；
2024-04-20 V0.4.7 更改gitee地址
2024-04-20 V0.4.8 增加OTA进度条；修复部分字体
2024-04-20 V0.4.9 增加旋转编码器限位值、反向自定义配置，以适配不同编码器
2024-04-20 V0.4.10 WifiManager增加旋转编码器配置
2024-04-28 V0.4.11 修复BUG
2024-05-02 V0.4.12 优化天气查询流程
2024-05-02 V0.4.13 Webserver查询剩余ROM解耦合
2024-05-03 V0.4.14 增加N16R2分区表
    [custom_16MB.csv]
2024-05-04 V0.4.15 修改默认配置；修复BUG
2024-05-04 V0.4.16 优化设置相关
2024-05-04 V0.5.0 增加照片播放功能及相关自定义配置【N16R2适配】
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2024-05-05 V0.6.1 Web配置页增加头图
    [config_mijia.txt]
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2024-05-05 V0.6.3 修复双击；优化气象预警
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2024-05-06 V0.7.2 更换键盘字体
    (cherry picked from commit 20362a8706d957d222fd6e410ca60a7743fe614d)
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2024-05-07 更新项目目录
    [config_mijia.txt, config_stocks.txt, config_web.txt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]
2024-05-08 更新项目文档、3D打印文件
    [主体外壳.STL, 主体盖板.STL, 外壳主体.STL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]
2024-05-08 更新项目文档
    [额外BOM.xlsx]
2024-05-08 更新项目硬件文件
    [BOM_【主板】TripleKey主板_2024-05-09.xlsx, BOM_【拓展方案1】米家及人在传感器拓展_2024-05-09.xlsx, BOM_【拓展方案2】右侧拓展板_2024-05-09.xlsx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]
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2024-05-11 更新BOM
    [BOM_【主板】TripleKey主板_2024-05-09.xlsx, 额外BOM.xlsx]
2024-05-11 V0.8.3 修复不接拓展无法启动的BUG
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2024-05-23 V0.9.4 正式版发布前最终准备
    [config_mijia.txt, config_web.txt]
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2024-06-05 更新新米家拓展方案；更新项目文档。
    [BOM_【拓展方案3】米家及人在传感器拓展_贴_2024-06-05.xlsx, 主体盖板.STL, 屏幕按键外壳x3.STL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]
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2024-06-10 V1.1.0 优化米家功能；优化米家配置方式；优化设置页样式
    [config_mijia.txt, config_stocks.txt]
2024-06-25 更新外壳3D文件
    [新版主体外壳.STL]
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2024-07-03 更新FDM打印模型；更新文档
    [OrcaSlicer切片摆盘.3mf, 主体外壳FDM.STEP, 主体盖板.STL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]
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2024-07-27 更新3D文件
    [主体盖板FDM.STEP]
2025-04-29 V1.2.0 更新适配和风天气新API
    [OrcaSlicer切片摆盘.3mf, config_stocks.txt]
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2025-05-13 V1.2.1 修复更改天气配置导致无法开机的问题
2025-05-13 V1.2.1 修复更改天气配置导致无法开机的问题（更新固件）
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
